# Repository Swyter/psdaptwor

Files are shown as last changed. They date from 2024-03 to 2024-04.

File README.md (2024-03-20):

# What is `psdaptwor`?
An experimental PC adapter for EPCOT —the PlayStation®VR2 headset— that splits USB Type-C® into DisplayPort video, USB 3 data and power. Intercepting its DP-AUX/SBU and CC side channels.

> **Important**: *This is my first electronics project and I am still ironing the whole thing out, I have gotten here with a lot of hints and reviews from people who actually know what they are doing, but it should be considered non-functional, for now.*

# How do I get one?
Once the project is properly tested and the design is finalized we will provide the manufacturing files to order assembled boards from any affordable printed circuit board (PCB) fabrication house.
The final aim of the project is that one assembled adapter should cost less than 50€; the design and components are being aggresively optimized as much as possible. Getting one or two should be feasible for almost anyone.

# What does it look like?
More or less like this, the dimensions are around *6.3 x 10.2 centimeters*; much tinier than it looks like here:

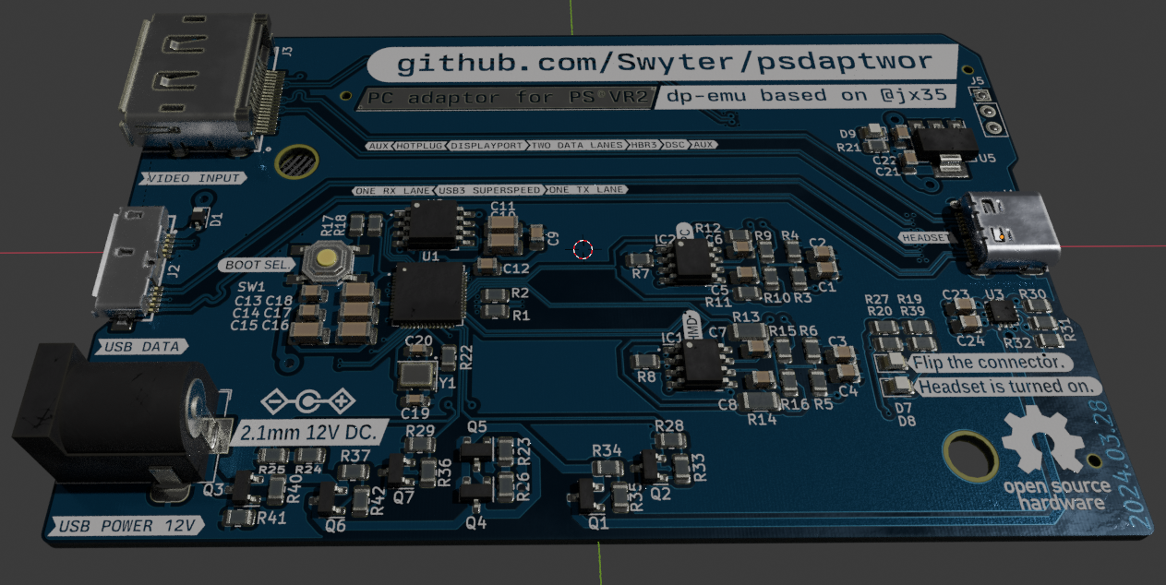
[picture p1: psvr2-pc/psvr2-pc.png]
imagen


# What is that name? Do you know how to spell?

No, it is not a typo. I needed something that could be unique and searchable, and contained `PS`, `VR` and `two` somewhere.
Sony products (like the memory card USB one) seem to call their adapters adaptors, so I follow their naming scheme.  

You can call it the *pee ess virtual adaptor*. :)

# Credits and acknowledgements
* *`@JX35`*: For the *DisplayPort AUX emulator* board this is heavily based on, and uncountable references, ideas and suggestions.
* *`@mrandTX`*: Hardware reviews, many suggestions, things I wouldn't have even thought about and encouragement.
* *`@thaytan`, `@ivry.vr` and many others around the Monado project*: Crucial research and development about how the PS®VR2 hardware and software actually functions. Standing on the shoulders of giants, this just cobbles stuff together. Many thanks.
* *[`jorticus/DPSwitch`](https://github.com/jorticus/DPSwitch)*, for the initial DisplayPort symbols and schematic that I used as a start point to learn the program and a good reference of how to use KiCad buses to group signals.
* *[`diva-eng/diva-card`](https://github.com/diva-eng/diva-card)*, for the known-good 12 MHz 20pF crystal oscillator circuit using cheap JLCPCB basic parts, and the capacitor/resistor values.

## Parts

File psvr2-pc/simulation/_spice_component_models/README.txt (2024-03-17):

https://www.nexperia.com/products/bipolar-transistors/general-purpose-and-low-vcesat-bipolar-transistors/single-bipolar-transistors/single-bipolar-transistors-100-v/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
https://assets.nexperia.com/documents/spice-model/MMBT2222A.txt

https://github.com/rdmeneze/LTSpiceModels/blob/master/AO3401A.mod

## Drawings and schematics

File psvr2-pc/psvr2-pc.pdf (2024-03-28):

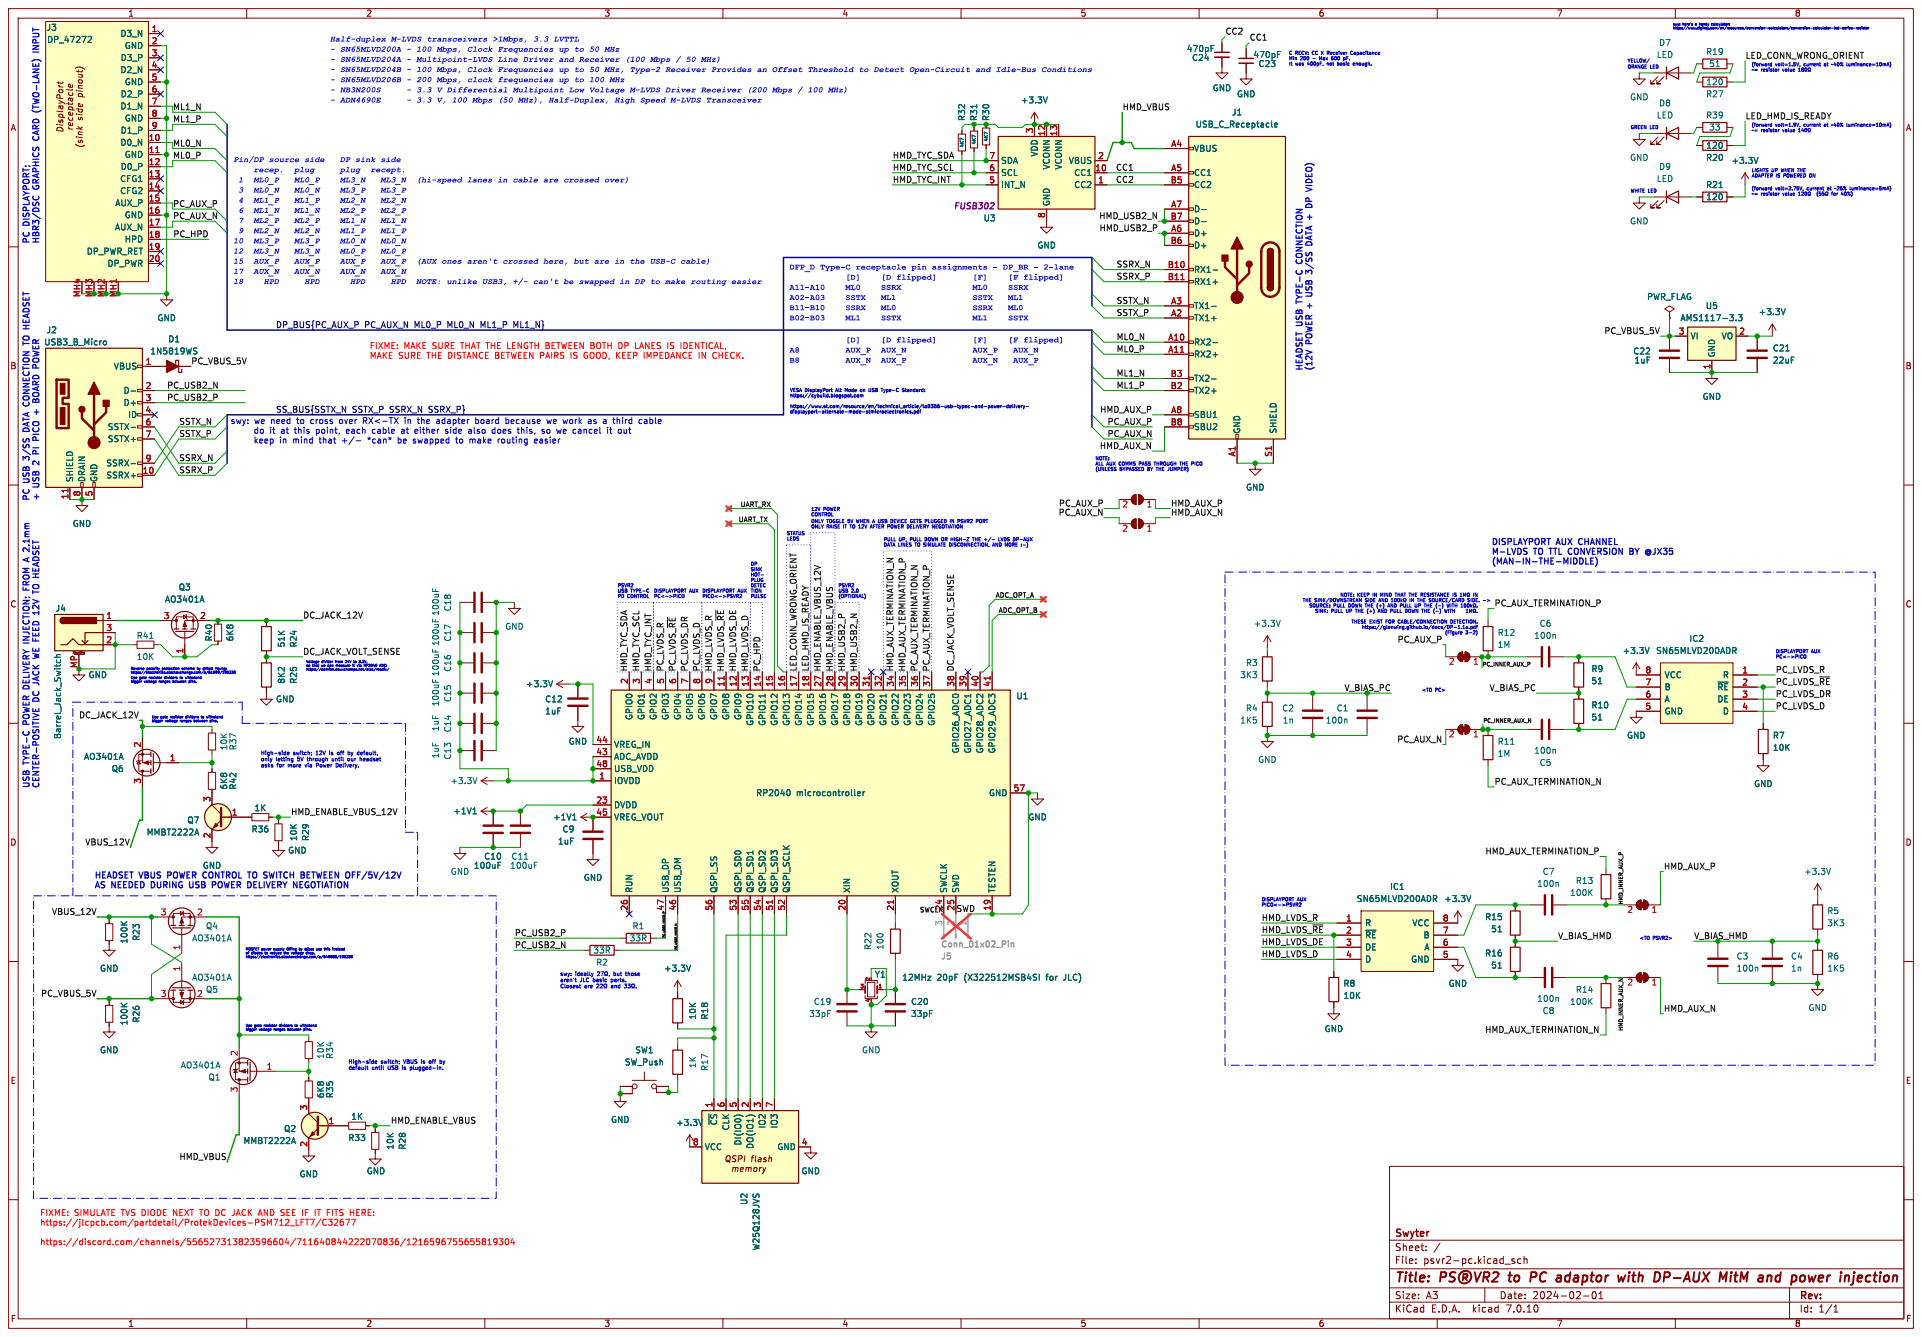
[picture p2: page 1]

(sink side pinout) GND 11 CFG1 13 CFG2 14 AUX_P 15 GND 16 AUX_N 17 HPD 18 DP_PWR_RET 19 GND 2 DP_PWR 20 GND 5 GND 8 MH4 MH3 MH2 MH1 D3_N 1 D0_N 10 D0_P 12 D3_P 3 D2_N 4 D2_P 6 D1_N 7 D1_P 9

- SN65MLVD200A - 100 Mbps, Clock Frequencies up to 50 MHz

C RECV: CC X Receiver Capacitance Min 200 þÿ"Max 600 pF.

1 R32 4K7 R30 4K7 R31 4K7 +3.3V U3 FUSB302 CC2 1 CC1 VCONN 10 12 VCONN 13 VBUS VDD 2

LIGHTS UP WHEN THE ADAPTER IS POWERED ON GREEN LED WHITE LED

+ USB 2 PI PICO + BOARD POWER

https://www.st.com/resource/en/technical_article/ta0356-usb-typec-and-power-delivery- displayport-alternate-mode-stmicroelectronics.pdf

NOTE: ALL AUX COMMS PASS THROUGH THE PICO

CONTROL HEADSET VBUS POWER CONTROL TO SWITCH BETWEEN OFF/5V/12V AS NEEDED DURING USB POWER DELIVERY NEGOTIATION

(Figure 3-2) ONLY TOGGLE 5V WHEN A USB DEVICE GETS PLUGGED IN PSVR2 PORT ONLY RAISE IT TO 12V AFTER POWER DELIVERY NEGOTIATION

NOTE: KEEP IN MIND THAT THE RESISTANCE IS þÿ1M©IN

2 XIN 20 XOUT 21 DVDD 23 SWCLK 24 SWD 25 RUN 26 GPIO16 27 GPIO17 28 GPIO18 29 GPIO1

<TO PSVR2> FIXME: SIMULATE TVS DIODE NEXT TO DC JACK AND SEE IF IT FITS HERE: https://jlcpcb.com/partdetail/ProtekDevices-PSM712_LFT7/C32677

Id: 1/1 Title: þÿPS®VR2 to PC adaptor with DP-AUX MitM and power injection

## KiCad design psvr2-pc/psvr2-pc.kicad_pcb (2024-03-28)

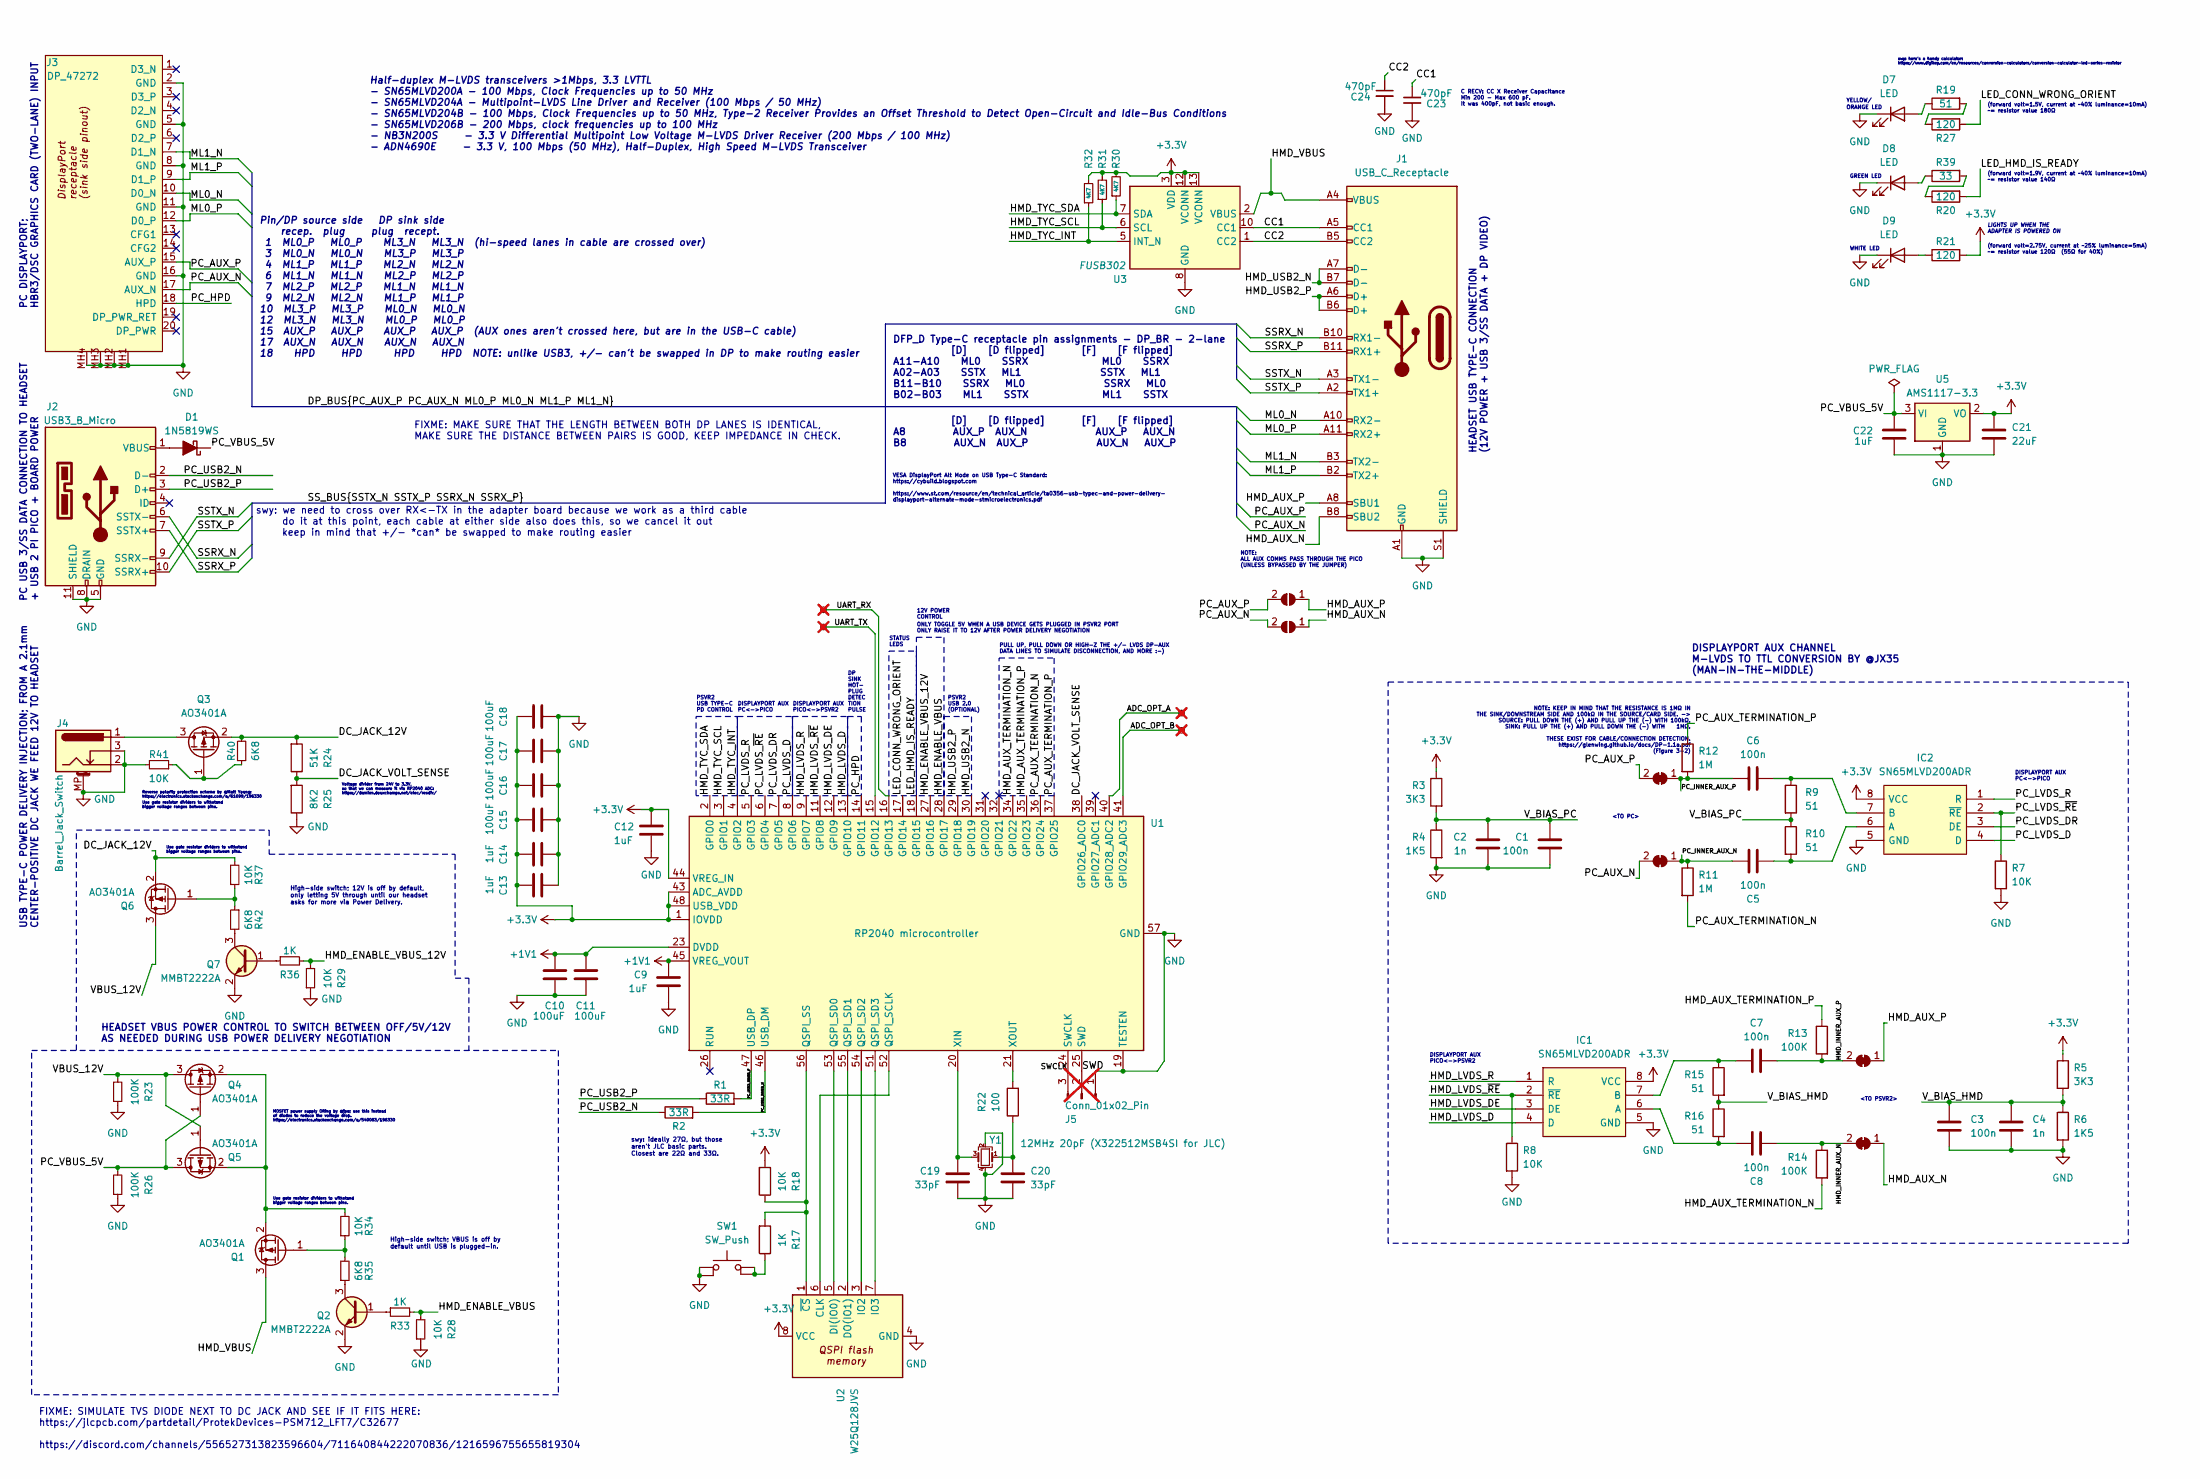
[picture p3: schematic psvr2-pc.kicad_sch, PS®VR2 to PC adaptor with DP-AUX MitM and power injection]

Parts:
C1, C3, C5, C6, C7, C8: 100n; C_0805_2012Metric
C2, C4: 1n; C_0805_2012Metric
C9, C12, C13, C14, C22: 1uF; C_0805_2012Metric
C10, C11, C15, C16, C17, C18: 100uF; C_1206_3216Metric
C19: 33pF; C_0603_1608Metric_Pad1.08x0.95mm_HandSolder; Mfr. Part # CL10C330JB8NNNC; LCSC Part # C1663
C20: 33pF; C_0603_1608Metric_Pad1.08x0.95mm_HandSolder; Mfr. Part # CL10C330JB8NNNC; JLCPCB Part # C1663
C21: 22uF; C_0805_2012Metric
C23, C24: 470pF; C_0805_2012Metric; LCSC Part # C1743
D1: 1N5819WS; D_SOD-323; Mfr. Part # 1N5819WS; LCSC Part # C191023
D7: LED; LED_0805_2012Metric; Mfr. Part # KT-0805Y; LCSC Part # C2296
D8: LED; LED_0805_2012Metric; Mfr. Part # KT-0805G; LCSC Part # C2297
D9: LED; LED_0805_2012Metric; Mfr. Part # KT-0805W; LCSC Part # C34499
IC1, IC2: SN65MLVD200ADR; SOIC-8_3.9x4.9mm_P1.27mm; Manufacturer_Part_Number SN65MLVD200ADR; Mouser Part Number 595-SN65MLVD200A
J1: USB_C_Receptacle; USB-C-SMD_TYPE-C-USB-18; Mfr. Part # MOLEX-1054500101; LCSC Part # C134092
J2: USB3_B_Micro; USB-SMD_692622030100
J3: DP_47272; CONN-SMD_472720001; LCSC Part # C587824
J4: Barrel_Jack_Switch; BarrelJack_Horizontal; Mfr. Part # DC-470-2.1GP; LCSC Part # C194407
J5: Conn_01x02_Pin; PinHeader_1x03_P2.54mm_Vertical; not fitted
JP1, JP2: SolderJumper_2_Open; SolderJumper-2_P1.3mm_Open_Pad1.0x1.5mm
JP3, JP5, JP6: SolderJumper_2_CLOSED; SolderJumper-2_P1.3mm_Bridged_RoundedPad1.0x1.5mm
JP4: SolderJumper_2_Open; SolderJumper-2_P1.3mm_Bridged_RoundedPad1.0x1.5mm
Q1, Q3, Q4, Q5, Q6: AO3401A; SOT-23; Mfr. Part # SI2301CDS-T1-GE3; JLCPCB Rotation Offset 180
Q2, Q7: MMBT2222A; SOT-23; Mfr. Part # MMBT2222A 1P; JLCPCB Rotation Offset 180
R1, R2: 33R; R_0805_2012Metric
R3, R5: 3K3; R_0805_2012Metric
R4, R6: 1K5; R_0805_2012Metric
R7, R8, R18, R28, R29, R34, R37, R41: 10K; R_0805_2012Metric
R9, R10, R15, R16, R19: 51; R_0805_2012Metric
R11, R12: 1M; R_0805_2012Metric
R13, R14: 100K; R_1206_3216Metric
R17, R33, R36: 1K; R_0805_2012Metric
R20, R21, R27: 120; R_0805_2012Metric
R22: 100; R_0805_2012Metric
R23, R26: 100K; R_0805_2012Metric
R24: 51K; R_0805_2012Metric
R25: 8K2; R_0805_2012Metric
R30, R31, R32: 4K7; R_0805_2012Metric
R35, R40, R42: 6K8; R_0805_2012Metric
R39: 33; R_0805_2012Metric
SW1: SW_Push; SW-SMD_4P-L5.1-W5.1-P3.70-LS6.5-TL-2; Mfr. Part # TS-1187A-B-A-B; LCSC Part # C318884
TP1, TP2, TP3, TP4: TestPoint_Small; TestPoint_Pad_D2.5mm; not fitted
U1: RP2040 microcontroller; QFN-56-1EP_7x7mm_P0.4mm_EP3.2x3.2mm; Mfr. Part # RP2040; LCSC Part # C2040
U2: W25Q128JVS; SOIC-8_5.23x5.23mm_P1.27mm; Mfr. Part # W25Q128JVSIQ; LCSC Part # C97521
U3: FUSB302B01MPX; WQFN-14-1EP_2.5x2.5mm_P0.5mm_EP1.45x1.45mm; Mfr. Part # Fusb302mpx; LCSC Part # C442699
U5: AMS1117-3.3; SOT-223-3_TabPin2; Mfr. Part # AMS1117-3.3; LCSC Part # C6186
Y1: 12MHz 20pF (X322512MSB4SI for JLC); Crystal_SMD_3225-4Pin_3.2x2.5mm; Mfr. Part # X322512MSB4SI; LCSC Part # C9002

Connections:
+1V1: C9.1, C10.1, C11.1, U1.23 (DVDD), U1.45 (VREG_VOUT), U1.50 (DVDD)
+3.3V: C12.1, C13.2, C14.2, C15.2, C16.2, C17.2, C18.2, C21.1, IC1.8 (VCC), IC2.8 (VCC), R3.1, R5.1, R18.2, R21.2, R30.2, R31.2, R32.2, U1.1 (IOVDD), U1.10 (IOVDD), U1.22 (IOVDD), U1.33 (IOVDD), U1.42 (IOVDD), U1.43 (ADC_AVDD), U1.44 (VREG_IN), U1.48 (USB_VDD), U1.49 (IOVDD), U2.8 (VCC), U3.3 (VDD), U3.4 (VDD), U3.12 (VCONN), U3.13 (VCONN), U5.2 (VO)
/ADC_OPT_A: TP3.1, U1.40 (GPIO28_ADC2)
/ADC_OPT_B: TP4.1, U1.41 (GPIO29_ADC3)
/CC1: C23.1, J1.A5 (CC1), U3.10 (CC1), U3.11 (CC1)
/CC2: C24.1, J1.B5 (CC2), U3.1 (CC2), U3.14 (CC2)
/DC_JACK_12V: Q3.2 (S), Q6.2 (S), R24.2, R37.2, R40.2
/DC_JACK_VOLT_SENSE: R24.1, R25.2, U1.38 (GPIO26_ADC0)
/HMD_AUX_N: J1.B8 (SBU2), JP2.1 (A), JP4.1 (A)
/HMD_AUX_P: J1.A8 (SBU1), JP1.1 (A), JP3.1 (A)
/HMD_AUX_TERMINATION_N: R14.2, U1.34 (GPIO22)
/HMD_AUX_TERMINATION_P: R13.1, U1.35 (GPIO23)
/HMD_ENABLE_VBUS: R28.2, R33.2, U1.28 (GPIO17)
/HMD_ENABLE_VBUS_12V: R29.2, R36.2, U1.27 (GPIO16)
/HMD_INNER_AUX_N: C8.2, JP4.2 (B), R14.1
/HMD_INNER_AUX_P: C7.2, JP3.2 (B), R13.2
/HMD_LVDS_D: IC1.4 (D), U1.13 (GPIO10)
/HMD_LVDS_DE: IC1.3 (DE), U1.12 (GPIO9)
/HMD_LVDS_R: IC1.1 (R), U1.9 (GPIO7)
/HMD_LVDS_~RE: IC1.2 (~RE), R8.1, U1.11 (GPIO8)
/HMD_TYC_INT: R32.1, U1.4 (GPIO2), U3.5 (INT_N)
/HMD_TYC_SCL: R31.1, U1.3 (GPIO1), U3.6 (SCL)
/HMD_TYC_SDA: R30.1, U1.2 (GPIO0), U3.7 (SDA)
/HMD_USB2_N: J1.A7 (D-), J1.B7 (D-), U1.30 (GPIO19)
/HMD_USB2_P: J1.A6 (D+), J1.B6 (D+), U1.29 (GPIO18)
/HMD_VBUS: J1.A4 (VBUS), J1.A9 (VBUS), J1.B4 (VBUS), J1.B9 (VBUS), Q1.3 (D), U3.2 (VBUS)
/LED_CONN_WRONG_ORIENT: R27.2, U1.17 (GPIO14)
/LED_HMD_IS_READY: R20.2, U1.18 (GPIO15)
/ML0_N: J1.A10 (RX2-), J3.10 (D0_N)
/ML0_P: J1.A11 (RX2+), J3.12 (D0_P)
/ML1_N: J1.B3 (TX2-), J3.7 (D1_N)
/ML1_P: J1.B2 (TX2+), J3.9 (D1_P)
/PC_AUX_N: J3.17 (AUX_N), JP2.2 (B), JP6.2 (B)
/PC_AUX_P: J3.15 (AUX_P), JP1.2 (B), JP5.2 (B)
/PC_AUX_TERMINATION_N: R11.2, U1.36 (GPIO24)
/PC_AUX_TERMINATION_P: R12.1, U1.37 (GPIO25)
/PC_HPD: J3.18 (HPD), U1.14 (GPIO11)
/PC_INNER_AUX_N: C5.2, JP6.1 (A), R11.1
/PC_INNER_AUX_P: C6.2, JP5.1 (A), R12.2
/PC_LVDS_D: IC2.4 (D), U1.8 (GPIO6)
/PC_LVDS_DR: IC2.3 (DE), U1.7 (GPIO5)
/PC_LVDS_R: IC2.1 (R), U1.5 (GPIO3)
/PC_LVDS_~RE: IC2.2 (~RE), R7.1, U1.6 (GPIO4)
/PC_USB2_INNER_N: R2.2, U1.46 (USB_DM)
/PC_USB2_INNER_P: R1.2, U1.47 (USB_DP)
/PC_USB2_N: J2.2 (D-), R2.1
/PC_USB2_P: J2.3 (D+), R1.1
/PC_VBUS_5V: C22.1, D1.1 (K), Q4.1 (G), Q5.3 (D), R26.2, U5.3 (VI)
/SSRX_N: J1.B10 (RX1-), J2.6 (SSTX-)
/SSRX_P: J1.B11 (RX1+), J2.7 (SSTX+)
/SSTX_N: J1.A3 (TX1-), J2.9 (SSRX-)
/SSTX_P: J1.A2 (TX1+), J2.10 (SSRX+)
/SWCLK: J5.3, U1.24 (SWCLK)
/SWD: J5.2, U1.25 (SWD)
/UART_RX: TP2.1, U1.16 (GPIO13)
/UART_TX: TP1.1, U1.15 (GPIO12)
/VBUS_12V: Q4.3 (D), Q5.1 (G), Q6.3 (D), R23.2
/V_BIAS_HMD: C3.1, C4.1, R5.2, R6.1, R15.2, R16.1
/V_BIAS_PC: C1.1, C2.1, R3.2, R4.1, R9.2, R10.1
GND: C1.2, C2.2, C3.2, C4.2, C9.2, C10.2, C11.2, C12.2, C13.1, C14.1, C15.1, C16.1, C17.1, C18.1, C19.2, C20.2, C21.2, C22.2, C23.2, C24.2, D7.1 (K), D8.1 (K), D9.1 (K), IC1.5 (GND), IC2.5 (GND), J1.0, J1.A1 (GND), J1.A12 (GND), J1.B1 (GND), J1.B12 (GND), J1.S1 (SHIELD), J2.5 (GND), J2.8 (DRAIN), J2.11 (SHIELD), J3.2 (GND), J3.5 (GND), J3.8 (GND), J3.11 (GND), J3.16 (GND), J3.21, J3.22, J3.23, J3.24, J3.MH1, J3.MH2, J3.MH3, J3.MH4, J4.2, J4.3, J4.MP (MountPin), J5.1, Q2.2 (E), Q7.2 (E), R4.2, R6.2, R7.2, R8.2, R23.1, R25.1, R26.1, R28.1, R29.1, R41.2, SW1.1, SW1.2, U1.19 (TESTEN), U1.57 (GND), U2.4 (GND), U3.8 (GND), U3.9 (GND), U3.15 (GND), U5.1 (GND), Y1.2, Y1.4
unnamed: C20.1, R22.1, Y1.1
unnamed: D1.2 (A), J2.1 (VBUS)
unnamed: D7.2 (A), R19.1
unnamed: D8.2 (A), R39.1
unnamed: D9.2 (A), R21.1
unnamed: C8.1, IC1.6 (A), R16.2
unnamed: C7.1, IC1.7 (B), R15.1
unnamed: C5.1, IC2.6 (A), R10.2
unnamed: C6.1, IC2.7 (B), R9.1
unnamed: Q1.1 (G), R34.1, R35.2
unnamed: Q1.2 (S), Q4.2 (S), Q5.2 (S), R34.2
unnamed: Q2.1 (B), R33.1
unnamed: Q2.3 (C), R35.1
unnamed: J4.1, Q3.3 (D)
unnamed: Q3.1 (G), R40.1, R41.1
unnamed: Q6.1 (G), R37.1, R42.1
unnamed: Q7.1 (B), R36.1
unnamed: Q7.3 (C), R42.2
unnamed: R17.1, SW1.3, SW1.4
unnamed: R19.2, R27.1
unnamed: R20.1, R39.2
unnamed: U1.52 (QSPI_SCLK), U2.6 (CLK)
unnamed: U1.53 (QSPI_SD0), U2.5 (DI(IO0))
unnamed: U1.55 (QSPI_SD1), U2.2 (DO(IO1))
unnamed: U1.54 (QSPI_SD2), U2.3 (IO2)
unnamed: U1.51 (QSPI_SD3), U2.7 (IO3)
unnamed: R17.2, R18.1, U1.56 (QSPI_SS), U2.1 (~CS)
unnamed: C19.1, U1.20 (XIN), Y1.3
unnamed: R22.2, U1.21 (XOUT)

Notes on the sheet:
Reverse polarity protection scheme by @Matt Young: https://electronics.stackexchange.com/a/61699/196330
NOTE: ALL AUX COMMS PASS THROUGH THE PICO (UNLESS BYPASSED BY THE JUMPER)
MOSFET power supply ORing by @jpa; use this instead of diodes to reduce the voltage drop. https://electronics.stackexchange.com/a/549083/196330
VESA DisplayPort Alt Mode on USB Type-C Standard: https://cybuild.blogspot.com https://www.st.com/resource/en/technical_article/ta0356-usb-typec-and-power-delivery- displayport-alternate-mode-stmicroelectronics.pdf
(forward volt=1.5V, current at ~40% luminance=10mA) ~= resistor value 180Ω
C RECV: CC X Receiver Capacitance Min 200 − Max 600 pF. It was 400pF, not basic enough.
DP SINK HOT- PLUG DETEC TION PULSE
HEADSET USB TYPE-C CONNECTION (12V POWER + USB 3/SS DATA + DP VIDEO)
DISPLAYPORT AUX CHANNEL M-LVDS TO TTL CONVERSION BY @JX35 (MAN-IN-THE-MIDDLE)
swy: we need to cross over RX<-TX in the adapter board because we work as a third cable do it at this point, each cable at either side also does this, so we cancel it out keep in mind that +/- *can* be swapped to make routing easier
DISPLAYPORT AUX PICO<->PSVR2
HEADSET VBUS POWER CONTROL TO SWITCH BETWEEN OFF/5V/12V AS NEEDED DURING USB POWER DELIVERY NEGOTIATION
WHITE LED
DISPLAYPORT AUX PC<->PICO
Voltage divider from 24V to 3.3V, so that we can measure it via RP2040 ADC: https://damien.douxchamps.net/elec/resdiv/
<TO PC>
12V POWER CONTROL
FIXME: MAKE SURE THAT THE LENGTH BETWEEN BOTH DP LANES IS IDENTICAL, MAKE SURE THE DISTANCE BETWEEN PAIRS IS GOOD, KEEP IMPEDANCE IN CHECK.
<TO PSVR2>
[D] [D flipped] [F] [F flipped] A8 AUX_P AUX_N AUX_P AUX_N B8 AUX_N AUX_P AUX_N AUX_P
Use gate resistor dividers to withstand bigger voltage ranges between pins.
High-side switch; 12V is off by default, only letting 5V through until our headset asks for more via Power Delivery.
YELLOW/
PULL UP, PULL DOWN OR HIGH-Z THE +/- LVDS DP-AUX DATA LINES TO SIMULATE DISCONNECTION, AND MORE :-)
(forward volt=2.75V, current at ~25% luminance=5mA) ~= resistor value 120Ω (55Ω for 40%)
(forward volt=1.9V, current at ~40% luminance=10mA) ~= resistor value 140Ω
ONLY TOGGLE 5V WHEN A USB DEVICE GETS PLUGGED IN PSVR2 PORT ONLY RAISE IT TO 12V AFTER POWER DELIVERY NEGOTIATION
ORANGE LED
swy: here's a handy calculator: https://www.digikey.com/en/resources/conversion-calculators/conversion-calculator-led-series-resistor
swy: ideally 27Ω, but those aren't JLC basic parts. Closest are 22Ω and 33Ω.
FIXME: SIMULATE TVS DIODE NEXT TO DC JACK AND SEE IF IT FITS HERE: https://jlcpcb.com/partdetail/ProtekDevices-PSM712_LFT7/C32677 https://discord.com/channels/556527313823596604/711640844222070836/1216596755655819304
PSVR2 USB 2.0 (OPTIONAL)
USB TYPE-C POWER DELIVERY INJECTION; FROM A 2.1mm CENTER-POSITIVE DC JACK WE FEED 12V TO HEADSET
Pin/DP source side DP sink side recep. plug plug recept. 1 ML0_P ML0_P ML3_N ML3_N (hi-speed lanes in cable are crossed over) 3 ML0_N ML0_N ML3_P ML3_P 4 ML1_P ML1_P ML2_N ML2_N 6 ML1_N ML1_N ML2_P ML2_P 7 ML2_P ML2_P ML1_N ML1_N 9 ML2_N ML2_N ML1_P ML1_P 10 ML3_P ML3_P ML0_N ML0_N 12 ML3_N ML3_N M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
Half-duplex M-LVDS transceivers >1Mbps, 3.3 LVTTL - SN65MLVD200A - 100 Mbps, Clock Frequencies up to 50 MHz - SN65MLVD204A - Multipoint-LVDS Line Driver and Receiver (100 Mbps / 50 MHz) - SN65MLVD204B - 100 Mbps, Clock Frequencies up to 50 MHz, Type-2 Receiver Provides an Offset Threshold to Detect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
STATUS LEDS
PC USB 3/SS DATA CONNECTION TO HEADSET + USB 2 PI PICO + BOARD POWER
NOTE: KEEP IN MIND THAT THE RESISTANCE IS 1MΩ IN THE SINK/DOWNSTREAM SIDE AND 100kΩ IN THE SOURCE/CARD SIDE. -> SOURCE: PULL DOWN THE (+) AND PULL UP THE (-) WITH 100kΩ. SINK: PULL UP THE (+) AND PULL DOWN THE (-) WITH 1MΩ. THESE EXIST FOR CABLE/CONNECTION DETECTION. https://glenwing.github.io/docs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
High-side switch; VBUS is off by default until USB is plugged-in.
DFP_D Type-C receptacle pin assignments - DP_BR - 2-lane [D] [D flipped] [F] [F flipped] A11-A10 ML0 SSRX ML0 SSRX A02-A03 SSTX ML1 SSTX ML1 B11-B10 SSRX ML0 SSRX ML0 B02-B03 ML1 SSTX ML1 SSTX

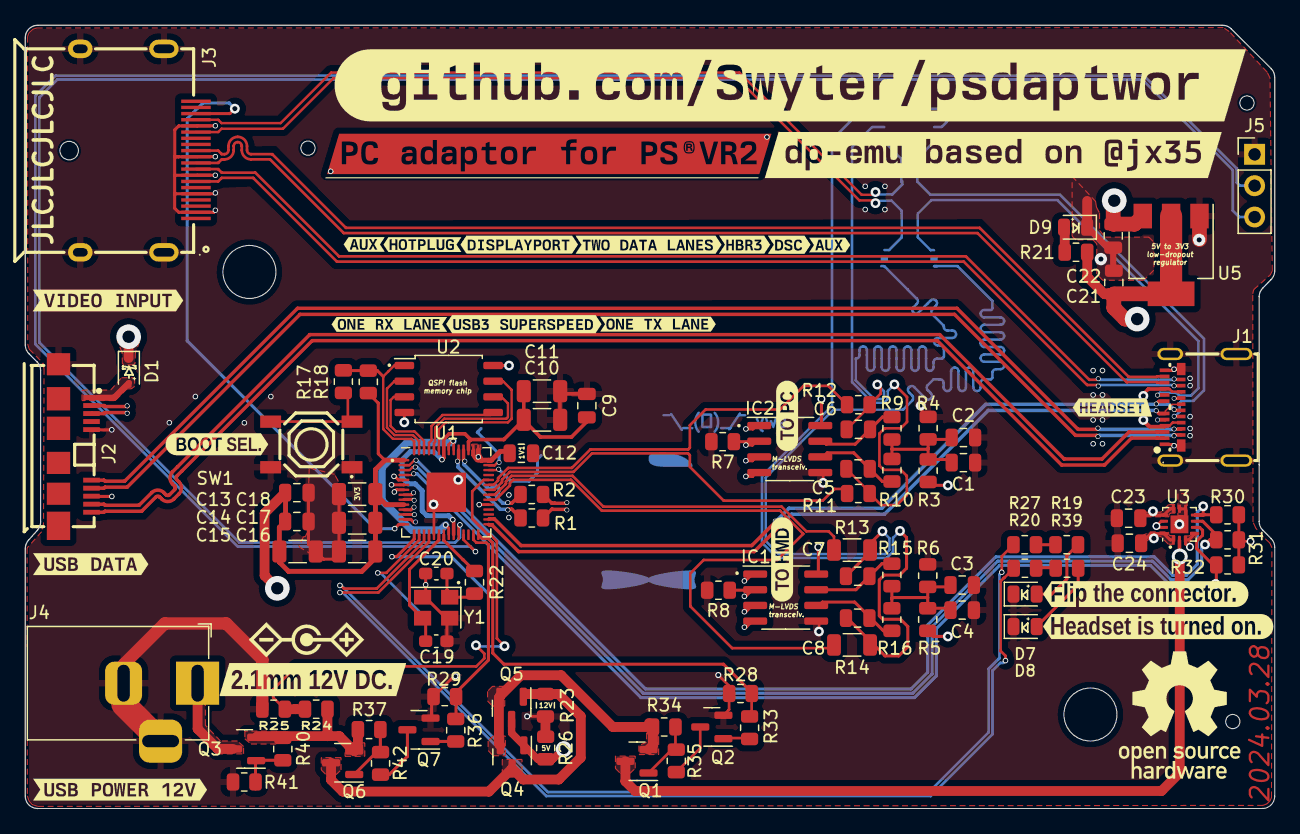
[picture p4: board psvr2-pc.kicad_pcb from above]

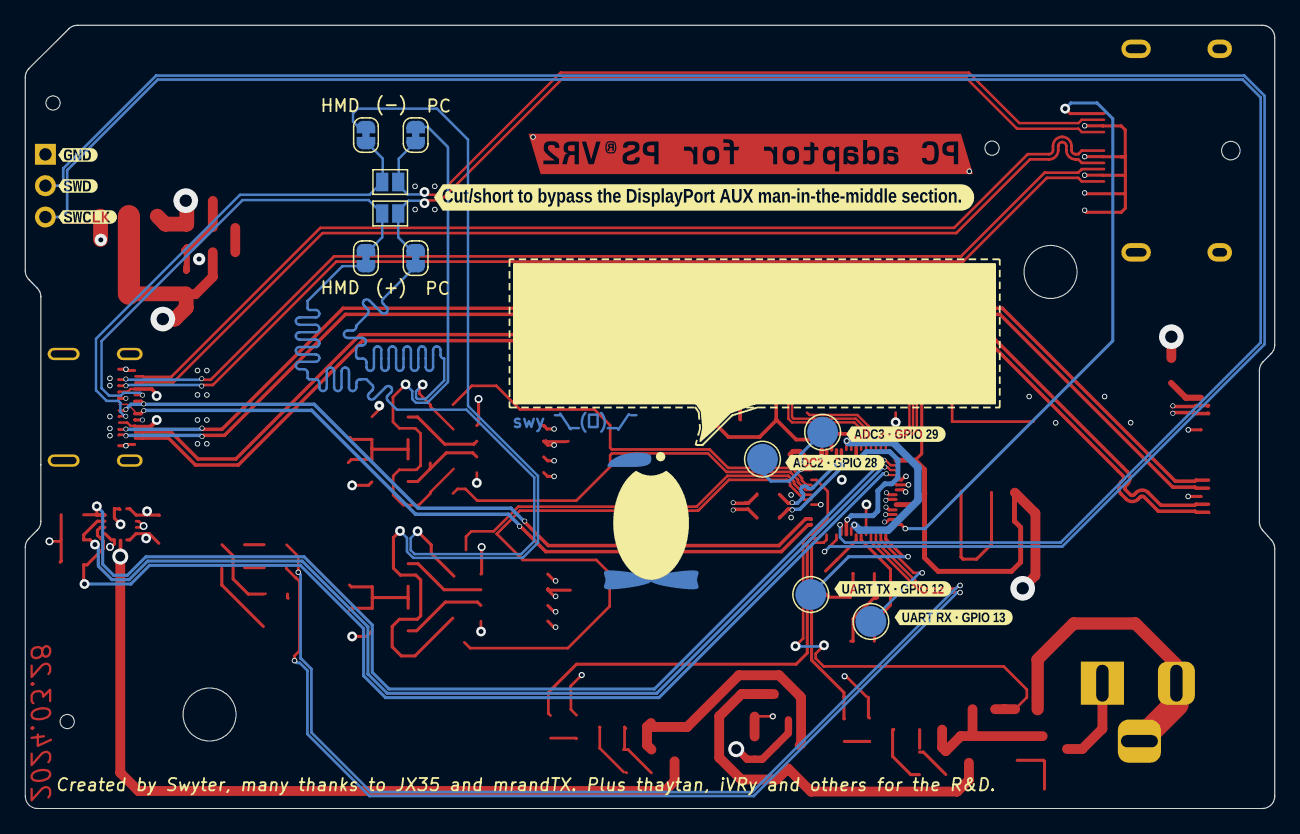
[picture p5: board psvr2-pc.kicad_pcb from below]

Board: 4 copper layers, 101.3 x 63.5 mm, 135 parts (18 on the bottom side), 89 nets.

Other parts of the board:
M4_MOUNT_HOLE_DOWN, M4_MOUNT_HOLE_UP: MountingHole_4.3mm_M4
SMT_BOTTOM_RIGHT: MountingHole_2.1mm
SMT_TOP_LEFT: MountingHole_2.1mm
SMT_TOP_RIGHT: MountingHole_2.1mm
kibuzzard-65C6E5E2: G***; kibuzzard-65C6E5E2
kibuzzard-65C6E540: G***; kibuzzard-65C6E540
kibuzzard-65C0700D: G***; kibuzzard-65C0700D
kibuzzard-65C07004: G***; kibuzzard-65C07004
kibuzzard-65C07017: G***; kibuzzard-65C07017
kibuzzard-65E1F822: G***; kibuzzard-65E1F822
kibuzzard-65E1F853: G***; kibuzzard-65E1F853
kibuzzard-65E1FEE7: G***; kibuzzard-65E1FEE7
kibuzzard-65E1FEEE: G***; kibuzzard-65E1FEEE
kibuzzard-65E1FFC8: G***; kibuzzard-65E1FFC8
kibuzzard-65E7A09E: G***; kibuzzard-65E7A09E
kibuzzard-65E7A091: G***; kibuzzard-65E7A091
kibuzzard-65E7B531: G***; kibuzzard-65E7B531
kibuzzard-65E009D7: G***; kibuzzard-65E009D7
kibuzzard-65E024DE: G***; kibuzzard-65E024DE
kibuzzard-65E0054E: G***; kibuzzard-65E0054E
kibuzzard-65E91FE7: G***; kibuzzard-65E91FE7
kibuzzard-65E539B1: G***; kibuzzard-65E539B1
kibuzzard-65E00649: G***; kibuzzard-65E00649
kibuzzard-65E00656: G***; kibuzzard-65E00656
kibuzzard-65E00723: G***; kibuzzard-65E00723
kibuzzard-65E00862: G***; kibuzzard-65E00862
kibuzzard-65E00873: G***; kibuzzard-65E00873
kibuzzard-65E00902: G***; kibuzzard-65E00902
kibuzzard-65E00968: G***; kibuzzard-65E00968
kibuzzard-65E01491: G***; kibuzzard-65E01491
kibuzzard-65E20367: G***; kibuzzard-65E20367
kibuzzard-65EB850B: G***; kibuzzard-65EB850B
kibuzzard-65EB8511: G***; kibuzzard-65EB8511
kibuzzard-65F67D58: G***; kibuzzard-65F67D58
kibuzzard-65F683C1: G***; kibuzzard-65F683C1

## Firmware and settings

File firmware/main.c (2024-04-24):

/**
 * | psdaptwor - an experimental PSVR2 to PC adaptor | firmware
 * | created by Swyter <swyterzone+psdaptwor@gmail.com>
 *
 * SPDX-License-Identifier: GPL-2.0-or-later
 */

#include <stdio.h>
#include <stdlib.h>
#include <string.h>
#include <tusb.h>
#include "pico/stdlib.h"
#include "hardware/gpio.h"
#include "hardware/adc.h"

#include "pico/binary_info.h"
#include "hardware/i2c.h"

#include "fusb302_defines.h"
//#include "pd.h"

/*      Main microcontroller chip: https://datasheets.raspberrypi.com/rp2040/rp2040-datasheet.pdf
                                   https://datasheets.raspberrypi.com/rp2040/hardware-design-with-rp2040.pdf

        Type-C PD controller chip: https://www.onsemi.com/pdf/datasheet/fusb302b-d.pdf
                                   https://github.com/Ralim/usb-pd/
                                   https://www.ti.com/lit/an/slva704/slva704.pdf (good overview of how the I2C protocol works)
                                   https://github.com/ReclaimerLabs/FUSB302/blob/master/FUSB302.cpp (The Google ChromeOS EC implementation; very clean and well-commented)
                                   https://hackaday.com/2023/02/14/all-about-usb-c-talking-low-level-pd/ (init and receiving PD messages as a UFP/sink)
                                   https://hackaday.com/2023/02/22/all-about-usb-c-replying-low-level-pd/ (sending [accept] messages)
                                   https://github.com/CRImier/AltmodeFriend/blob/main/main.py (RP2040 micropython implementation from the Hackaday author)

   M-LVDS to TTL transceiver chip: http://www.ti.com/lit/gpn/SN65MLVD200 */

enum psdaptwor_pins
{
    PSDAPT_PIN_HMD_TYC_SDA           =  0, /* swy: I2C connection to FUSB302B Type-C Power Delivery control chip */
    PSDAPT_PIN_HMD_TYC_SCL           =  1,
    PSDAPT_PIN_HMD_TYC_INT           =  2,
          
    PSDAPT_PIN_PC_LVDS_R             =  3, /* swy: M-LVDS transceiver data in-out for both DisplayPort AUX sides */
    PSDAPT_PIN_PC_LVDS_RE            =  4,
    PSDAPT_PIN_PC_LVDS_DR            =  5,
    PSDAPT_PIN_PC_LVDS_D             =  6,
          
    PSDAPT_PIN_HMD_LVDS_R            =  7,
    PSDAPT_PIN_HMD_LVDS_RE           =  8,
    PSDAPT_PIN_HMD_LVDS_DR           =  9,
    PSDAPT_PIN_HMD_LVDS_D            = 10,

    /* -- */

    PSDAPT_PIN_PC_HPD                = 11, /* swy: DisplayPort hot-plug detection pulse signal */
//  PSDAPT_PIN_12_UNUSED             = 12,
//  PSDAPT_PIN_13_UNUSED             = 13,

    PSDAPT_PIN_LED_CONN_WRONG_ORIENT = 14, /* swy: status LEDS; wrong-type-c-orientation is orange */
    PSDAPT_PIN_LED_HMD_IS_READY      = 15, /*                           headset-is-ready is green  */

    PSDAPT_PIN_HMD_ENABLE_VBUS_12V   = 16, /* swy: control the power switches by software as needed to enable */
    PSDAPT_PIN_HMD_ENABLE_VBUS       = 17, /*      the higher 12V DC jack voltage/5V from PC/off              */

    PSDAPT_PIN_HMD_USB2_P            = 18, /* swy: connected to the headset's USB 2.0 +/- pair, optional, in case we want to */
    PSDAPT_PIN_HMD_USB2_N            = 19, /*      relay it to the host PC via PIO, or inspect the billboard device          */
//  PSDAPT_PIN_20_UNUSED             = 20,
//  PSDAPT_PIN_21_UNUSED             = 21,

    PSDAPT_PIN_AUX_TERMINATION_N     = 22, /* swy: M-LVDS transceiver software-defined pull-up and pull-down resistors */
    PSDAPT_PIN_AUX_TERMINATION_P     = 23,
    PSDAPT_PIN_PC_AUX_TERMINATION_N  = 24,
    PSDAPT_PIN_PC_AUX_TERMINATION_P  = 25,

    PSDAPT_PIN_DC_JACK_VOLT_SENSE    = 26, /* swy: analog-to-digital converter pins */
//  PSDAPT_PIN_27_UNUSED             = 27,
    PSDAPT_PIN_ADC_OPT_A             = 28,
    PSDAPT_PIN_ADC_OPT_B             = 29,
};

// I2C reserves some addresses for special purposes. We exclude these from the scan.
// These are any addresses of the form 000 0xxx or 111 1xxx

bool reserved_addr(uint8_t addr) {
    return (addr & 0x78) == 0 || (addr & 0x78) == 0x78;
}
 

/* swy: I2C register reading/writing functions from: https://forums.raspberrypi.com/viewtopic.php?p=2040653#p2040598 */
// Read bytes from a register
int i2c_read(
    i2c_inst_t *i2c,   // i2c0 or i2c1
    uint8_t i2c_addr,  // 7 bit I2C address
    uint8_t reg,       // Number of the register to read from
    uint8_t *rx_data,  // Pointer to block of bytes for data read
    uint8_t len        // Number of bytes of data to read
) {
    if (i2c_write_blocking(i2c, i2c_addr, &reg, 1, true) != 1) {
        return PICO_ERROR_GENERIC;
    }

    if (i2c_read_blocking(i2c, i2c_addr, rx_data, len, false) != len) {
        return PICO_ERROR_GENERIC;
    }

    return PICO_OK;
}

int i2c_read_byte(
    i2c_inst_t *i2c,   // i2c0 or i2c1
    uint8_t i2c_addr,  // 7 bit I2C address
    uint8_t reg,       // Number of the register to read from
    uint8_t *rx_data   // Pointer to block of bytes for data read
) {
    return i2c_read(i2c, i2c_addr, reg, rx_data, 1);
}

// Write bytes to a register
int i2c_write(
    i2c_inst_t *i2c,         // i2c0 or i2c1
    uint8_t i2c_addr,        // 7 bit I2C address 
    uint8_t reg,             // Number of the register to write to
    const uint8_t *tx_data,  // Pointer to block of bytes to write
    uint8_t len              // Length of block of bytes to write
) {
    uint8_t tx_len = len + 1;
    uint8_t tx_buf[tx_len];
    tx_buf[0]  = reg;
    memcpy(&tx_buf[1], tx_data, len);

    if (i2c_write_blocking(i2c, i2c_addr, tx_buf, tx_len, false) != tx_len) {
        return PICO_ERROR_GENERIC;
    }

    return PICO_OK;
}

int i2c_write_byte(
    i2c_inst_t *i2c,         // i2c0 or i2c1
    uint8_t i2c_addr,        // 7 bit I2C address 
    uint8_t reg,             // Number of the register to write to
    uint8_t tx_byte          // Byte to write
) {
    uint8_t tx_buf = tx_byte; return i2c_write(i2c, i2c_addr, reg, &tx_buf, 1);
}


char *fusb_debug_register(uint8_t reg, uint8_t reg_data)
{
    uint8_t reg_data_orig = reg_data;

#define CASE_PRINT(_REG) \
    case _REG: printf("[%s]: ", &#_REG[5]);

#define PRINT_REG(ARG_PREFIX, ARG_NAME) /* swy: if the flag is set, print it, to see if we need to print a | separator make sure the current flag is set and there's any set data underneath that will be processed afterwards, or we'll just print the number */ \
    printf("%s%s", (reg_data & ARG_PREFIX##_##ARG_NAME) ? #ARG_NAME : "", (reg_data & ARG_PREFIX##_##ARG_NAME) && (reg_data & (ARG_PREFIX##_##ARG_NAME - 1)) ? "|" : ""); reg_data &= ~ARG_PREFIX##_##ARG_NAME;

#define CASE_END() \
    if (reg_data != 0 || reg_data_orig==reg_data) printf("%#x, ", reg_data); /* swy: if there's any remaining unparsed data, or no flags have been processed, i.e. it's zero, print the number */ \
                                             else printf(  ", "); \
    break;

    switch (reg)
    {
        default:
            printf("[??? Unknown register %X], ", reg);
            break;

        CASE_PRINT(FUSB_SWITCHES0) {
            PRINT_REG(FUSB_SWITCHES0, CC2_PU_EN)
            PRINT_REG(FUSB_SWITCHES0, CC1_PU_EN)
            PRINT_REG(FUSB_SWITCHES0, VCONN_CC2)
            PRINT_REG(FUSB_SWITCHES0, VCONN_CC1)
            PRINT_REG(FUSB_SWITCHES0, MEAS_CC2 )
            PRINT_REG(FUSB_SWITCHES0, MEAS_CC1 )
            PRINT_REG(FUSB_SWITCHES0, CC2_PD_EN)
            PRINT_REG(FUSB_SWITCHES0, CC1_PD_EN)
            CASE_END()
        }

        CASE_PRINT(FUSB_SWITCHES1) {
            PRINT_REG(FUSB_SWITCHES1, POWERROLE)
            PRINT_REG(FUSB_SWITCHES1, SPECREV1 )
            PRINT_REG(FUSB_SWITCHES1, SPECREV0 )
            PRINT_REG(FUSB_SWITCHES1, DATAROLE )
            PRINT_REG(FUSB_SWITCHES1, AUTO_CRC )
            PRINT_REG(FUSB_SWITCHES1, TXCC2_EN )
            PRINT_REG(FUSB_SWITCHES1, TXCC1_EN )
            CASE_END()
        }

        CASE_PRINT(FUSB_CONTROL0) {
            PRINT_REG(FUSB_CONTROL0, TX_FLUSH )
            PRINT_REG(FUSB_CONTROL0, INT_MASK )
            PRINT_REG(FUSB_CONTROL0, HOST_CUR1)
            PRINT_REG(FUSB_CONTROL0, HOST_CUR0)
            PRINT_REG(FUSB_CONTROL0, AUTO_PRE )
            PRINT_REG(FUSB_CONTROL0, TX_START )
            CASE_END()
        }

        CASE_PRINT(FUSB_CONTROL1) {
            PRINT_REG(FUSB_CONTROL1, ENSOP2DB  )
            PRINT_REG(FUSB_CONTROL1, ENSOP1DB  )
            PRINT_REG(FUSB_CONTROL1, BIST_MODE2)
            PRINT_REG(FUSB_CONTROL1, RX_FLUSH  )
            PRINT_REG(FUSB_CONTROL1, ENSOP2    )
            PRINT_REG(FUSB_CONTROL1, ENSOP1    )
            CASE_END()
        }

        CASE_PRINT(FUSB_CONTROL2) {
            PRINT_REG(FUSB_CONTROL2, TOG_SAVE_PWR1)
            PRINT_REG(FUSB_CONTROL2, TOG_SAVE_PWR0)
            PRINT_REG(FUSB_CONTROL2, TOG_RD_ONLY  )
            PRINT_REG(FUSB_CONTROL2, WAKE_EN      )
            PRINT_REG(FUSB_CONTROL2, MODE1        )
            PRINT_REG(FUSB_CONTROL2, MODE0        )
            PRINT_REG(FUSB_CONTROL2, TOGGLE       )
            CASE_END()
        }

        CASE_PRINT(FUSB_CONTROL3) {
            PRINT_REG(FUSB_CONTROL3, SEND_HARD_RESET)
            PRINT_REG(FUSB_CONTROL3, BIST_TMODE     )
            PRINT_REG(FUSB_CONTROL3, AUTO_HARDRESET )
            PRINT_REG(FUSB_CONTROL3, AUTO_SOFTRESET )
            PRINT_REG(FUSB_CONTROL3, N_RETRIES1     )
            PRINT_REG(FUSB_CONTROL3, N_RETRIES0     )
            PRINT_REG(FUSB_CONTROL3, AUTO_RETRY     )
            CASE_END()
        }

        CASE_PRINT(FUSB_POWER) {
            PRINT_REG(FUSB_POWER, PWR3)
            PRINT_REG(FUSB_POWER, PWR2)
            PRINT_REG(FUSB_POWER, PWR1)
            PRINT_REG(FUSB_POWER, PWR0)
            CASE_END()
        }

        CASE_PRINT(FUSB_STATUS0A) {
            PRINT_REG(FUSB_STATUS0A, SOFTFAIL )
            PRINT_REG(FUSB_STATUS0A, RETRYFAIL)
            PRINT_REG(FUSB_STATUS0A, POWER3   )
            PRINT_REG(FUSB_STATUS0A, POWER2   )
            PRINT_REG(FUSB_STATUS0A, SOFTRST  )
            PRINT_REG(FUSB_STATUS0A, HARDRST  )
            CASE_END()
        }

        CASE_PRINT(FUSB_STATUS1A) {
            PRINT_REG(FUSB_STATUS1A, TOGSS_SHIFT)
            PRINT_REG(FUSB_STATUS1A, TOGSS      )
            PRINT_REG(FUSB_STATUS1A, RXSOP2DB   )
            PRINT_REG(FUSB_STATUS1A, RXSOP1DB   )
            PRINT_REG(FUSB_STATUS1A, RXSOP      )
            CASE_END()
        }

        CASE_PRINT(FUSB_INTERRUPTA) {
            PRINT_REG(FUSB_INTERRUPTA, I_OCP_TEMP )
            PRINT_REG(FUSB_INTERRUPTA, I_TOGDONE  )
            PRINT_REG(FUSB_INTERRUPTA, I_SOFTFAIL )
            PRINT_REG(FUSB_INTERRUPTA, I_RETRYFAIL)
            PRINT_REG(FUSB_INTERRUPTA, I_HARDSENT )
            PRINT_REG(FUSB_INTERRUPTA, I_TXSENT   )
            PRINT_REG(FUSB_INTERRUPTA, I_SOFTRST  )
            PRINT_REG(FUSB_INTERRUPTA, I_HARDRST  )
            CASE_END()
        }

        CASE_PRINT(FUSB_INTERRUPTB) {
            PRINT_REG(FUSB_INTERRUPTB, I_GCRCSENT)
            CASE_END()
        }

        CASE_PRINT(FUSB_STATUS0) {
            PRINT_REG(FUSB_STATUS0, VBUSOK  )
            PRINT_REG(FUSB_STATUS0, ACTIVITY)
            PRINT_REG(FUSB_STATUS0, COMP    )
            PRINT_REG(FUSB_STATUS0, CRC_CHK )
            PRINT_REG(FUSB_STATUS0, ALERT   )
            PRINT_REG(FUSB_STATUS0, WAKE    )
            PRINT_REG(FUSB_STATUS0, BC_LVL1 )
            PRINT_REG(FUSB_STATUS0, BC_LVL0 )
            CASE_END()
        }

        CASE_PRINT(FUSB_STATUS1) {
            PRINT_REG(FUSB_STATUS1, RXSOP2  )
            PRINT_REG(FUSB_STATUS1, RXSOP1  )
            PRINT_REG(FUSB_STATUS1, RX_EMPTY)
            PRINT_REG(FUSB_STATUS1, RX_FULL )
            PRINT_REG(FUSB_STATUS1, TX_EMPTY)
            PRINT_REG(FUSB_STATUS1, TX_FULL )
            PRINT_REG(FUSB_STATUS1, OVRTEMP )
            PRINT_REG(FUSB_STATUS1, OCP     )
            CASE_END()
        }

        CASE_PRINT(FUSB_INTERRUPT) {
            PRINT_REG(FUSB_INTERRUPT, I_VBUSOK   )
            PRINT_REG(FUSB_INTERRUPT, I_ACTIVITY )
            PRINT_REG(FUSB_INTERRUPT, I_COMP_CHNG)
            PRINT_REG(FUSB_INTERRUPT, I_CRC_CHK  )
            PRINT_REG(FUSB_INTERRUPT, I_ALERT    )
            PRINT_REG(FUSB_INTERRUPT, I_WAKE     )
            PRINT_REG(FUSB_INTERRUPT, I_COLLISION)
            PRINT_REG(FUSB_INTERRUPT, I_BC_LVL   )
            CASE_END()
        }

    }
#undef CASE_END
#undef PRINT_REG
#undef CASE_PRINT
}

uint32_t fusb_interrupt_callback_happened = 0;
uint8_t dat_int_a, dat_int_b, dat_int, dat_stat1;
bool run_replug = true;

absolute_time_t before = 0;

void fusb_interrupt_callback(uint gpio, uint32_t event_mask)
{
    before = get_absolute_time();printf("\nget_absolute_time %lu\n", before);
    fusb_interrupt_callback_happened = event_mask;
}


int fusb_measure_against(int mdac_val)
{
    uint8_t rxdata, ret = i2c_write_byte(i2c_default, FUSB302B_ADDR, FUSB_MEASURE, FUSB_MEASURE_MEAS_VBUS | (mdac_val & 0b111111)); //printf("f write ret: %#x, counter: %x, comp volt: %f\n", ret, mdac_val, mdac_val * 0.420f);
    i2c_read(i2c_default, FUSB302B_ADDR, FUSB_STATUS0, &rxdata, 1); //printf("i2c_read FUSB_STATUS0: %#x COMP: %u\n", rxdata, (rxdata & FUSB_STATUS0_COMP));
    return (rxdata & FUSB_STATUS0_COMP);
}

int fusb_measure_vbus_bsearch_comp(const void *a, const void *b)
{
    long unsigned int index = (long unsigned int) b;

    if ((fusb_measure_against(index) & FUSB_STATUS0_COMP) && index < (FUSB_MEASURE_MDAC + 1))
        return (fusb_measure_against(index + 1) == 0) ? 0 : +1;

    return -1;
}
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
int main() {
    stdio_init_all();
    stdio_usb_init();
    stdio_usb_connected();
    printf("ADC Example, measuring GPIO26\n");

    set_sys_clock_khz(160000, true);

#ifndef PICO_DEFAULT_LED_PIN
#warning blink example requires a board with a regular LED
#else
    const uint LED_PIN = PICO_DEFAULT_LED_PIN;
    gpio_init   (PSDAPT_PIN_LED_CONN_WRONG_ORIENT);
    gpio_set_dir(PSDAPT_PIN_LED_CONN_WRONG_ORIENT, GPIO_OUT);
    gpio_put    (PSDAPT_PIN_LED_CONN_WRONG_ORIENT, 1);

    gpio_init   (PSDAPT_PIN_LED_HMD_IS_READY);
    gpio_set_dir(PSDAPT_PIN_LED_HMD_IS_READY, GPIO_OUT);
    gpio_put    (PSDAPT_PIN_LED_HMD_IS_READY, 1);
#endif

    gpio_init   (PSDAPT_PIN_HMD_ENABLE_VBUS);
    gpio_set_dir(PSDAPT_PIN_HMD_ENABLE_VBUS, GPIO_OUT);
    gpio_put    (PSDAPT_PIN_HMD_ENABLE_VBUS,     0);

    gpio_init   (PSDAPT_PIN_HMD_ENABLE_VBUS_12V);
    gpio_set_dir(PSDAPT_PIN_HMD_ENABLE_VBUS_12V, GPIO_OUT);
    gpio_put    (PSDAPT_PIN_HMD_ENABLE_VBUS_12V, 0);

    gpio_init   (PSDAPT_PIN_PC_HPD);
    gpio_set_dir(PSDAPT_PIN_PC_HPD, GPIO_OUT);
    gpio_put    (PSDAPT_PIN_PC_HPD, 0);

    gpio_init         (PSDAPT_PIN_HMD_USB2_P);
    gpio_set_dir      (PSDAPT_PIN_HMD_USB2_P, GPIO_IN);
    gpio_disable_pulls(PSDAPT_PIN_HMD_USB2_P);
    gpio_init         (PSDAPT_PIN_HMD_USB2_N);
    gpio_set_dir      (PSDAPT_PIN_HMD_USB2_N, GPIO_IN);
    gpio_disable_pulls(PSDAPT_PIN_HMD_USB2_N);

    sleep_ms(3500);    

    adc_init();

    // Make sure GPIO is high-impedance, no pullups etc
    adc_gpio_init(26);
    // Select ADC input 0 (GPIO26)
    adc_select_input(0);


    // This example will use I2C0 on the default SDA and SCL pins (GP4, GP5 on a Pico)
    i2c_init(i2c_default, 400000);
    gpio_set_function(PICO_DEFAULT_I2C_SDA_PIN, GPIO_FUNC_I2C);
    gpio_set_function(PICO_DEFAULT_I2C_SCL_PIN, GPIO_FUNC_I2C);
    gpio_pull_up(PICO_DEFAULT_I2C_SDA_PIN);
    gpio_pull_up(PICO_DEFAULT_I2C_SCL_PIN);
    // Make the I2C pins available to picotool
    bi_decl(bi_2pins_with_func(PICO_DEFAULT_I2C_SDA_PIN, PICO_DEFAULT_I2C_SCL_PIN, GPIO_FUNC_I2C));

    gpio_set_irq_enabled_with_callback(PSDAPT_PIN_HMD_TYC_INT, GPIO_IRQ_EDGE_FALL, true, fusb_interrupt_callback);


    printf("\nI2C Bus Scan test\n");
    printf("   0  1  2  3  4  5  6  7  8  9  A  B  C  D  E  F\n");
 
    for (int addr = 0; addr < (1 << 7); ++addr) {
        if (addr % 16 == 0) {
            printf("%02x ", addr);
        }
 
        // Perform a 1-byte dummy read from the probe address. If a slave
        // acknowledges this address, the function returns the number of bytes
        // transferred. If the address byte is ignored, the function returns
        // -1.
 
        // Skip over any reserved addresses.
        int ret = 0;
        uint8_t rxdata;
        absolute_time_t timeout = make_timeout_time_ms(50);

        if (reserved_addr(addr))
            ret = PICO_ERROR_GENERIC;
        else
            ret = i2c_read_blocking_until(i2c_default, addr, &rxdata, 1, false, timeout);
 
        printf(ret < 0 ? "." : "@");
        printf(addr % 16 == 15 ? "\n" : "  ");
    }

    printf("Done, for real. :-)\n");

    uint8_t rxdata, reg;

    i2c_read(i2c_default, FUSB302B_ADDR, FUSB_SWITCHES0, &rxdata, 1); printf("b read FUSB_SWITCHES0: %#x ", rxdata); fusb_debug_register(FUSB_SWITCHES0, rxdata); puts(NULL);
    i2c_read(i2c_default, FUSB302B_ADDR, FUSB_SWITCHES1, &rxdata, 1); printf("b read FUSB_SWITCHES1: %#x ", rxdata); fusb_debug_register(FUSB_SWITCHES1, rxdata); puts(NULL);
    i2c_read(i2c_default, FUSB302B_ADDR, FUSB_MEASURE,   &rxdata, 1); printf("b read FUSB_MEASURE: %#x\n", rxdata);

    init();
    set_cc(TYPEC_CC_RD); /* swy: this should not be needed, as it's the default; but mark us as the UFP/sink/peripheral device */
    i2c_read_byte(i2c_default, FUSB302B_ADDR, FUSB_CONTROL0, &reg); reg |= FUSB_CONTROL0_TX_FLUSH; i2c_write_byte(i2c_default, FUSB302B_ADDR, FUSB_CONTROL0, reg);
    /* Flush the RX buffer */
    i2c_read_byte(i2c_default, FUSB302B_ADDR, FUSB_CONTROL1, &reg); reg |= FUSB_CONTROL1_RX_FLUSH; i2c_write_byte(i2c_default, FUSB302B_ADDR, FUSB_CONTROL1, reg);

    pd_reset();

    int cc1_meas, cc2_meas;
    detect_cc_pin_sink(&cc1_meas, &cc2_meas);

    /* swy: send a hard reset packet to the other side to restart the PD conversation with anything already plugged-in */
    //i2c_read(i2c_default, FUSB302B_ADDR, FUSB_CONTROL3, &reg, 1); reg |= FUSB_CONTROL3_SEND_HARD_RESET;
    //i2c_write_byte(i2c_default, FUSB302B_ADDR, FUSB_CONTROL3, reg);

    i2c_read(i2c_default, FUSB302B_ADDR, FUSB_SWITCHES0, &rxdata, 1); printf("b read FUSB_SWITCHES0: %#x ", rxdata); fusb_debug_register(FUSB_SWITCHES0, rxdata); puts(NULL);
    i2c_read(i2c_default, FUSB302B_ADDR, FUSB_SWITCHES1, &rxdata, 1); printf("b read FUSB_SWITCHES1: %#x ", rxdata); fusb_debug_register(FUSB_SWITCHES1, rxdata); puts(NULL);
    i2c_read(i2c_default, FUSB302B_ADDR, FUSB_MEASURE,   &rxdata, 1); printf("b read FUSB_MEASURE: %#x\n", rxdata);

    uint8_t switchesBackup; i2c_read(i2c_default, FUSB302B_ADDR, FUSB_SWITCHES0, &switchesBackup, 1); printf("b read FUSB_SWITCHES0: %#x ", switchesBackup); fusb_debug_register(FUSB_SWITCHES0, switchesBackup); puts(NULL);
    uint8_t measureBackup;  i2c_read(i2c_default, FUSB302B_ADDR, FUSB_MEASURE,   &measureBackup,  1); printf("b read FUSB_MEASURE: %#x\n", measureBackup);
    uint8_t counter = 0, cc1 = 0, cc2 = 0, cc1_is_bigger_than_cc2 = 0; float measured_vbus = 0.f; bool cc_tx_configured = 0;

    uint32_t  usb_pd_message_header = 0x69;
    uint32_t  usb_pd_message_buffer[10] = {0x69}; int ret;

    uint8_t buf[32] = {0x69};

    

    while (1) {
        absolute_time_t from = get_absolute_time();
        if (fusb_interrupt_callback_happened)
        {
            printf("[i] reading interrupt registers\n");

            i2c_read(i2c_default, FUSB302B_ADDR, FUSB_INTERRUPTA, &dat_int_a, 1); fusb_debug_register(FUSB_INTERRUPTA, dat_int_a);
            i2c_read(i2c_default, FUSB302B_ADDR, FUSB_INTERRUPTB, &dat_int_b, 1); fusb_debug_register(FUSB_INTERRUPTB, dat_int_b); 
            i2c_read(i2c_default, FUSB302B_ADDR, FUSB_INTERRUPT,  &dat_int,   1); fusb_debug_register(FUSB_INTERRUPT,  dat_int  );
            i2c_read(i2c_default, FUSB302B_ADDR, FUSB_STATUS1,    &dat_stat1, 1); fusb_debug_register(FUSB_STATUS1,  dat_stat1  ); puts(NULL);

            printf("[i] ---\n");

            //if (dat_int & FUSB_INTERRUPT_I_VBUSOK)
            //    run_replug = true;

            fusb_interrupt_callback_happened = 0;
        }

        // 12-bit conversion, assume max value == ADC_VREF == 3.3 V
        const float conversion_factor = 3.3f / (1 << 12);
        //uint16_t result = adc_read();
        //printf("[adc] Raw value: 0x%03x, measured voltage: %f V, actual pre-divided voltage: %f V\n", result, result * conversion_factor, result * (24.f / (1 << 12)));

        

        i2c_read(i2c_default, FUSB302B_ADDR, FUSB_STATUS1,    &rxdata, 1); ret = 0;
        
        //if ((rxdata & FUSB_STATUS1_RX_EMPTY) == 0)
            ret = get_message(usb_pd_message_buffer, &usb_pd_message_header);

        //if (ret < 0)
        //    printf("[!] error in get_message() return=%i", ret);

        if((ret > 0))
        {
            printf("[typec] get_message: ret=%i, header=%x, ndataobj=%u, id=%u, pwrole=%u, specrev=%#x, datarole=%u type=%s/%#x buf=",
                ret, usb_pd_message_header, PD_HEADER_CNT(usb_pd_message_header), PD_HEADER_ID(usb_pd_message_header),
                 (usb_pd_message_header >> 8) & 0b1,
                 (usb_pd_message_header >> 6) & 0b11, /* swy: 0b00 -> 1.0, 0b01 -> 2.0, 0b10 -> 3.0 */
                 (usb_pd_message_header >> 5) & 0b1,
                str_pdmsgtype[PD_HEADER_CNT(usb_pd_message_header) > 0][PD_HEADER_TYPE(usb_pd_message_header)], PD_HEADER_TYPE(usb_pd_message_header)
            );

            unsigned char *buf = (unsigned char *) &usb_pd_message_buffer[0];
            for (int i = 0, max = (get_num_bytes(usb_pd_message_header) - 2) + 4; i < max; i++)
                printf("%02x %s", buf[i], ((i%4)==3) ? " " : "");

            puts(NULL);


            if (PD_HEADER_CNT(usb_pd_message_header) > 0 && PD_HEADER_TYPE(usb_pd_message_header) == 0x1) /* swy: SOURCE_CAPABILITIES/0x1 */
            {
               
            /*    for (int i = 0, max = PD_HEADER_CNT(usb_pd_message_header); i < max; i++)
                {
                    uint32_t cur_powerdataobj = (usb_pd_message_buffer[i]); uint32_t cur_powerdataobj_type =  (cur_powerdataobj >> 30) & 0b1111;
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

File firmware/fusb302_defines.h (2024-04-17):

#ifndef FUSB302_DEFINES
#define FUSB302_DEFINES
#include <stdint.h>

/* I2C addresses of the FUSB302B chips */
#define FUSB302B_ADDR   (0x22 /* << 1 */)
#define FUSB302B01_ADDR (0x23 /* << 1 */)
#define FUSB302B10_ADDR (0x24 /* << 1 */)
#define FUSB302B11_ADDR (0x25 /* << 1 */)

/* Device ID register */
#define FUSB_DEVICE_ID                   0x01
#define FUSB_DEVICE_ID_VERSION_ID_SHIFT  4
#define FUSB_DEVICE_ID_VERSION_ID        (0xF << FUSB_DEVICE_ID_VERSION_ID_SHIFT)
#define FUSB_DEVICE_ID_PRODUCT_ID_SHIFT  2
#define FUSB_DEVICE_ID_PRODUCT_ID        (0x3 << FUSB_DEVICE_ID_PRODUCT_ID_SHIFT)
#define FUSB_DEVICE_ID_REVISION_ID_SHIFT 0
#define FUSB_DEVICE_ID_REVISION_ID       (0x3 << FUSB_DEVICE_ID_REVISION_ID_SHIFT)

/* Switches0 register */
#define FUSB_SWITCHES0           0x02
#define FUSB_SWITCHES0_CC2_PU_EN (1 << 7) /* swy: was PU_EN2 */
#define FUSB_SWITCHES0_CC1_PU_EN (1 << 6) /* swy: was PU_EN1 */
#define FUSB_SWITCHES0_VCONN_CC2 (1 << 5)
#define FUSB_SWITCHES0_VCONN_CC1 (1 << 4)
#define FUSB_SWITCHES0_MEAS_CC2  (1 << 3)
#define FUSB_SWITCHES0_MEAS_CC1  (1 << 2)
#define FUSB_SWITCHES0_CC2_PD_EN (1 << 1) /* swy: was PDWN_2 */
#define FUSB_SWITCHES0_CC1_PD_EN 1        /* swy: was PDWN_1 */

/* Switches1 register */
#define FUSB_SWITCHES1               0x03
#define FUSB_SWITCHES1_POWERROLE     (1 << 7)
#define FUSB_SWITCHES1_SPECREV_SHIFT 5
#define FUSB_SWITCHES1_SPECREV       ( 0x3 << FUSB_SWITCHES1_SPECREV_SHIFT)
#define FUSB_SWITCHES1_SPECREV1      (0b10 << FUSB_SWITCHES1_SPECREV_SHIFT) /* swy: added this non-flag one */
#define FUSB_SWITCHES1_SPECREV0      (0b01 << FUSB_SWITCHES1_SPECREV_SHIFT) /* swy: added this non-flag one */
#define FUSB_SWITCHES1_DATAROLE      (1 << 4)
#define FUSB_SWITCHES1_AUTO_CRC      (1 << 2)
#define FUSB_SWITCHES1_TXCC2_EN      (1 << 1)
#define FUSB_SWITCHES1_TXCC1_EN      1

/* Measure register */
#define FUSB_MEASURE            0x04
#define FUSB_MEASURE_MEAS_VBUS  (1 << 6)
#define FUSB_MEASURE_MDAC_SHIFT 0
#define FUSB_MEASURE_MDAC       (0x3F << FUSB_MEASURE_MDAC_SHIFT)

/* Slice register */
#define FUSB_SLICE                0x05
#define FUSB_SLICE_SDAC_HYS_SHIFT 6
#define FUSB_SLICE_SDAC_HYS       (0x3 << FUSB_SLICE_SDAC_HYS_SHIFT)
#define FUSB_SLICE_SDAC_SHIFT     0
#define FUSB_SLICE_SDAC           (0x3F << FUSB_SLICE_SDAC_SHIFT)

/* Control0 register */
#define FUSB_CONTROL0                0x06
#define FUSB_CONTROL0_TX_FLUSH       (1 << 6)
#define FUSB_CONTROL0_INT_MASK       (1 << 5)
#define FUSB_CONTROL0_HOST_CUR_SHIFT 2
#define FUSB_CONTROL0_HOST_CUR       ( 0x3 << FUSB_CONTROL0_HOST_CUR_SHIFT)
#define FUSB_CONTROL0_HOST_CUR1      (0b10 << FUSB_CONTROL0_HOST_CUR_SHIFT) /* swy: added this non-flag one */
#define FUSB_CONTROL0_HOST_CUR0      (0b01 << FUSB_CONTROL0_HOST_CUR_SHIFT) /* swy: added this non-flag one */
#define FUSB_CONTROL0_AUTO_PRE       (1 << 1)
#define FUSB_CONTROL0_TX_START       1

/* Control1 register */
#define FUSB_CONTROL1            0x07
#define FUSB_CONTROL1_ENSOP2DB   (1 << 6)
#define FUSB_CONTROL1_ENSOP1DB   (1 << 5)
#define FUSB_CONTROL1_BIST_MODE2 (1 << 4)
#define FUSB_CONTROL1_RX_FLUSH   (1 << 2)
#define FUSB_CONTROL1_ENSOP2     (1 << 1)
#define FUSB_CONTROL1_ENSOP1     1

/* Control2 register */
#define FUSB_CONTROL2                    0x08
#define FUSB_CONTROL2_TOG_SAVE_PWR_SHIFT 6
#define FUSB_CONTROL2_TOG_SAVE_PWR       ( 0x3 << FUSB_CONTROL2_TOG_SAVE_PWR_SHIFT)
#define FUSB_CONTROL2_TOG_SAVE_PWR1      (0b10 << FUSB_CONTROL2_TOG_SAVE_PWR_SHIFT) /* swy: added this non-flag one */
#define FUSB_CONTROL2_TOG_SAVE_PWR0      (0b01 << FUSB_CONTROL2_TOG_SAVE_PWR_SHIFT) /* swy: added this non-flag one */
#define FUSB_CONTROL2_TOG_RD_ONLY        (1 << 5)
#define FUSB_CONTROL2_WAKE_EN            (1 << 3)
#define FUSB_CONTROL2_MODE_SHIFT         1
#define FUSB_CONTROL2_MODE               ( 0x3 << FUSB_CONTROL2_MODE_SHIFT)
#define FUSB_CONTROL2_MODE1              (0b10 << FUSB_CONTROL2_MODE_SHIFT) /* swy: added this non-flag one */
#define FUSB_CONTROL2_MODE0              (0b01 << FUSB_CONTROL2_MODE_SHIFT) /* swy: added this non-flag one */
#define FUSB_CONTROL2_TOGGLE             1

/* Control3 register */
#define FUSB_CONTROL3                 0x09
#define FUSB_CONTROL3_SEND_HARD_RESET (1 << 6)
#define FUSB_CONTROL3_BIST_TMODE      (1 << 5)
#define FUSB_CONTROL3_AUTO_HARDRESET  (1 << 4)
#define FUSB_CONTROL3_AUTO_SOFTRESET  (1 << 3)
#define FUSB_CONTROL3_N_RETRIES_SHIFT 1
#define FUSB_CONTROL3_N_RETRIES       ( 0x3 << FUSB_CONTROL3_N_RETRIES_SHIFT)
#define FUSB_CONTROL3_N_RETRIES1      (0b10 << FUSB_CONTROL3_N_RETRIES_SHIFT) /* swy: added this non-flag one */
#define FUSB_CONTROL3_N_RETRIES0      (0b01 << FUSB_CONTROL3_N_RETRIES_SHIFT) /* swy: added this non-flag one */
#define FUSB_CONTROL3_AUTO_RETRY      1
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

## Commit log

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2024-02-01 Fix the pin assignments to actually make sense and match unflipped D/F.
    [psvr2-pc.kicad_sch]
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2024-02-04 Start adding the missing footprints to the schematic and editing/assigning broken 3D models, play around with PCB placement.
    [psvr2-pc.kicad_pcb, psvr2-pc.kicad_sch]
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2024-02-05 Fix the micro USB footprint, rearrange the PCB now that more pieces appear. Add funkier labels.
    [psvr2-pc.kicad_pcb, psvr2-pc.kicad_sch]
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2024-02-05 Connect more stuff together, I don't know why the buses are still causing problems, even after using the name{thing thong thung} syntax.
    [psvr2-pc.kicad_pcb, psvr2-pc.kicad_sch]
2024-02-05 Start messing with the differential pairs, I wouldn't call this routing because freerouting plugin seems buggy as heck and causes phantom traces, great.
    [psvr2-pc.kicad_pcb]
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2024-02-05 Learn to work in multiple copper layers. Swap a differential pair at the beginning. Leave a ground plane sandwiched in the middle and always keep the high speed signals at both extremes.
    [psvr2-pc.kicad_pcb, psvr2-pc.kicad_sch]
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2024-02-06 Add clearance and board fabrication limits, or learning how stuff like annular width works. Add a nice open source hardware sticker in one corner, even if I'm not particularly raising the level here.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
    [psvr2-pc.kicad_pcb]
2024-02-06 Making it all worse due to the SSTX <-> SSRX crossing. The good thing is that the positive and negative wires in each individual lane can be swapped to make routing easier.
    [psvr2-pc.kicad_pcb, psvr2-pc.kicad_sch]
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2024-02-10 Begin to shorten the board horizontally, center the headset USB-C receptacle to make it look better. Make the drawings and labels more pretty.
    [psvr2-pc.kicad_pcb]
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2024-02-12 Had some time to re-try routing the differential signals. Hopefully with the real, final connections accounting for all the cable crossing. Now also taking into account the correct trace width + sepa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
    [psvr2-pc.kicad_pcb]
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2024-02-14 Add a switch button to enter flashing mode for the Pico/RP2040. Edit the PCB to add an indication of where the please-flip-me and am-I-on LEDs should go in the future.
    [psvr2-pc.kicad_pcb, psvr2-pc.kicad_sch]
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2024-02-14 Make the oscillator thingie better, grabbed the capacitor/resistor values from a known working board for JLC's YSX321SL:
    https://www.reddit.com/r/PrintedCircuitBoard/comments/vtjyqg/thanks_for_all_your_help_my_first_pcb_design_is/
    https://raw.githubusercontent.com/diva-eng/diva-card/main/schematic.pdf
    [psvr2-pc.kicad_sch]
2024-02-14 Fix PC_USB2.0_N and PC_USB2.0_P connecting into the opposite polarity pin of the Pico. Add two ground-stitching vias to the cosmetic cooper plane with the project description, to avoid possible RF is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
    [psvr2-pc.kicad_pcb, psvr2-pc.kicad_sch]
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2024-02-19 Fixes found by @mrandtx (Marc Randolph): Just got back to looking at this a bit more.
    Not sure what you need it for (I haven't read up on the RPi), but the SW1 botton won't work with the 10k in series. Too weak against the 1k. You could make it somewhere between 0 and 100 Ohms and it should be fine.
    Also I don't know if there is ever a case for TestEn to be anything except pulled to ground - but the connection to GND on this schematic isn't making contact. And I believe you already mentioned the 2.0 USB polarity.
    [psvr2-pc.kicad_sch]
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2024-02-24 Many fixes and tweaks; switch to power the 12V for the headset with a 2.1mm center-positive DC jack. Add a polarity-protection circuit and a diode OR for the 5V/12V join to work.
    [psvr2-pc.kicad_sch]
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2024-02-24 Start fixing some stuff in the schematic after some @JX35 feedback; use the correct JLCPCB 12MHz crystal oscillator part number. https://jlcpcb.com/partdetail/Yxc-X322512MSB4SI/C9002
    [psvr2-pc.kicad_sch]
2024-02-24 Start fixing some stuff in the schematic after some @JX35 feedback; use bigger resistor values in the 24V to 3.3V voltage divider. Use something that can withstand 4.404 mA of current.
    RATIO ERROR
    RL RH Rtot Current Power Ratio Vout Vin Absolute % ppm Tolerance (%)
    750 4K7 5450 4.404 mA 105.688 mW 0.137614679 3.302752294 23.980000000 -0.000114679 0.083 834 6.097985
    430 2K7 3130 7.668 mA 184.026 mW 0.137380192 3.297124601 24.020930233 0.000119808 -0.087 871 6.099643
    620 3K9 4520 5.310 mA 127.434 mW 0.137168142 3.292035398 24.058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
    [psvr2-pc.kicad_sch]
2024-02-25 Start fixing some stuff in the schematic after some @JX35 feedback; add 4K7 pull up resistors to the I2C type-C lines and small capacitors on the CC lines.
    [psvr2-pc.kicad_sch]
2024-02-25 Start fixing some stuff in the schematic after some @JX35 feedback; fix the crystal oscillator tag. Fix the wrong/badly copy-pasted 100M Ohms pull ups/down on the PC/sink side. We need to use 1M Ohm 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
    [psvr2-pc.kicad_sch]
2024-02-25 Start fixing some stuff in the schematic after some @JX35 feedback; try to fix the MOSFET power switch section and add some much-needed resistors. still need to properly simulate the whole power circ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
    - The 12V feedback resistors look to small to me, they'd burn 200mW at 12V; small SMD resistors can't handle that and it's a waste
    - The FUSB302 datasheet specifies 4K7 external pullups on the communication lines, I'd add them because internal pullups of MCUs are usually quite weak. It also specifies tiny capacitors on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
    [psvr2-pc.kicad_sch]
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2024-02-26 Mess around trying to give every component some kind of footprint, even if they are too big and impractical right now, to get a good intuition of what we would need to do, board-size wise.
    [psvr2-pc.kicad_pcb, psvr2-pc.kicad_sch]
2024-02-28 Change all the P MOSFETs to Si2301CDS_1_1, and use the correct SOT-23 footprint.
    [psvr2-pc.kicad_pcb, psvr2-pc.kicad_sch]
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2024-02-29 Start working on learning how to route normal components like the QSPI flash to the microcontroller. Fix the annular rings too big warnings.
    [psvr2-pc.kicad_pcb]
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2024-02-29 Mess around with the silkscreen art over the high-speed lanes and fix the ground plane at the edges.
    [psvr2-pc.kicad_pcb]
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2024-02-29 More routing, fix the funky USB2 main routing by moving it into the power layer, screw it.
    [psvr2-pc.kicad_pcb]
2024-02-29 Make the SWD pin header have another pin for ground. Reduce the DRC error count a bit more, add more track leeway, reduce polygon overlaps and add missing connections, mainly 3V3 power.
    [psvr2-pc.kicad_pcb, psvr2-pc.kicad_sch]
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2024-02-29 Swap to GPIOs to make routing slightly less messy. Make the Open Source Hardware logo line up with the 12V track. Other extra circuiting.
    [psvr2-pc.kicad_pcb, psvr2-pc.kicad_sch]
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2024-02-29 Fix the VBUS_5V net not getting renamed into the PCB editor from the schematic due to an error with the diode footprint. Change it and now it works. Add the 5V power traces and keep connecting more s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
    [psvr2-pc.kicad_pcb, psvr2-pc.kicad_sch]
2024-02-29 More DRC fixes, make the default annular size 0.4mm instead of 0.25. I messed up and all the new vias had this, causing a bunch of regressions. Almost there. :)
    [psvr2-pc.kicad_pcb]
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2024-03-01 Try to fix the third layer (power plane) to actually have a ground fill under/over the high-speed differential lines. route the SWD/SWCLK lines.
    [psvr2-pc.kicad_pcb]
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2024-03-01 Fix the last two or three clearance errors in the tiny traces moving inside the USB Type-C port.
    [psvr2-pc.kicad_pcb]
2024-03-01 Fix silk component tag overlap warnings and readability issues; move them around a bit.
    [psvr2-pc.kicad_pcb]
2024-03-01 Fix some overlapping component tags and make them readable. No more DRC errors or warnings. Yay! The next step is to look again at the schematic and flesh out the component footprints, double check t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
    [psvr2-pc.kicad_pcb]
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2024-03-01 Increase the via size to where it makes sense, and space is not too constrained. Mostly to .4mm, make the power vias also thicker. Fix the 90-degree corners in the AUX LVDS terminator traces, like Ma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
    > Nice. Minor comments: It's difficult to tell from the image, but the vias seems surprisingly close to the pads for U1 and U2. Guessing it's probably fine, and it just looks worse than it is. Even for low speed signals, 90 degree trace corners are rare (especially to the right of U1, and above C20) - to minimize questions from the board house, I'd try to chamfer them even a tiny bit - even if you have to slide R1 and R2 away a bit more (I say that with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
    [psvr2-pc.kicad_pcb]
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2024-03-01 Rename the switch component to SW1, fix the crystal footprint to use the actual one from JLC, instead of some smaller Abracom one I chose randomly. Add more JLC IDs, to the crystal and VBUX_5V to 3V3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
    [psvr2-pc.kicad_pcb, psvr2-pc.kicad_sch]
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2024-03-04 Add the USB Type-C Part # to the schematic. Edit the connector footprints to move the cutout lines into a different layer to avoid problems with the general board shape:
    https://forum.kicad.info/t/change-layer-of-multiple-selected-items-in-footprint-editor/12184/3
    https://forum.kicad.info/t/footprints-with-edge-cuts/35659
    Add a recessed cut for the micro USB thing, and move the DisplayPort thing a bit further into the edge to avoid problems. Haven't moved the traces yet, what a mess this whole footprint business is. :(
    [psvr2-pc.kicad_pcb, psvr2-pc.kicad_sch]
2024-03-04 Rework the power plane (third layer), which stopped losing contact in the 3V3 fill separated by that ground fill. Add some funny text tags in the copper as easter eggs. :)
    Fix DRC errors and warnings.
    [psvr2-pc.kicad_pcb]
2024-03-04 Make the filled out areas in all the layers more comprehensive, rounded, and giving enough margin from the cutout area to avoid shorting stuff out, like @mrandTX mentioned. Thanks to him.
    [psvr2-pc.kicad_pcb]
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2024-03-06 Fix the four switch pins for the BOOTSEL switch in the schematic. Make the DP-AUX jumpers have rounded corners. No more DRC violations again.
    [psvr2-pc.kicad_pcb, psvr2-pc.kicad_sch]
2024-03-06 Switch the footprint of the oscillator capacitors from 0805 to the smaller 0603 shape, add part numbers. As those are "basic" parts on JLC. Name the inner AUX traces before the jumpers so that we can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
    [psvr2-pc.kicad_pcb, psvr2-pc.kicad_sch]
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2024-03-06 Fix the DRC error for the AUX pair now touching the safety area for a close via before starting with the skew tunning and squiggles.
    [psvr2-pc.kicad_pcb]
2024-03-06 Fix all the reported ERC (the schematic error checker) problems. Mark a bunch of pins as not connected and move the power flag to the LDO (DC-DC 5V to 3V3 converter) to make it shut up.
    [psvr2-pc.kicad_sch]
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2024-03-07 Make the 3V3 status LED white and the headset ready one green. Now they are reversed. Use yellow for the flip connector LED instead of orange. Set the component IDs.
    [psvr2-pc.kicad_sch]
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2024-03-07 Get rid of the pin header 3D model by setting the scale to zero, fix the courtyard a bit, don't include it in the bill of materials: https://forum.kicad.info/t/how-to-remove-3d-model-but-keep-pads/28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
    [psvr2-pc.kicad_pcb, psvr2-pc.kicad_sch]
2024-03-07 Fix the white LED part number and use a much bigger resistor to make it dimmer. As this one is kind of strong. Hopefully things end up looking alright.
    [psvr2-pc.kicad_pcb, psvr2-pc.kicad_sch]
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2024-03-07 Update the LVDS-M transceiver chip to the correct A model, as @mrandTX said: SN65MLVD200ADR:
    --
    @mrandTX
    For anyone following along, and Swyter in particular, the following are all identical part numbers for 200A. R specifies that it comes in a tape and reel packaging. G4 is extra green, although in this case, saying G4 doesn't matter - you seem to get G4 regardless if you specify it.
    SN65MLVD200AD
    SN65MLVD200ADG4
    SN65MLVD200ADR
    SN65MLVD200ADRG4
    [psvr2-pc.kicad_sch]
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2024-03-09 More resistor adjustments to fit the real-life requirements of cheap components. Add two resistors in series to approximate the right current value in LEDs. Not happy with this, but what are you goin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
    [psvr2-pc.kicad_pcb, psvr2-pc.kicad_sch]
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2024-03-09 Change a few components to make them manufacturable at the lowest cost (basic ones). Change some footprints, add attributes to compensate for the wrong rotation and offset in many parts. Change a cap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
    DC 12 jack notes for the top-left cursor position:positions
    bad/before: 15.81, -58.9
    good/after: 12.83,-61.39
    >>> 12.83-15.81
    -2.9800000000000004
    >>> -61.39--58.9
    -2.490000000000002
    >>>
    [psvr2-pc.kicad_pcb, psvr2-pc.kicad_sch]
2024-03-09 Fix the wrong units being used in the 470u capacitors; they should be 470pF. Fix more JLC pick and place machine rotation compensation fields. Add more part number hints and use the right suffix for 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
    [psvr2-pc.kicad_pcb, psvr2-pc.kicad_sch]
2024-03-09 Fix the footprints in the schematic part, I only changed them in the PCB, so when sync'ing the schematic to the PCB it was erroring out and these components were skipped altogether. Add more LCSC par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
    [psvr2-pc.kicad_pcb, psvr2-pc.kicad_sch]
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2024-03-10 Hey, look. Got the power circuit simulation to work on KiCad 8 by starting a new project that uses the transistors in the simulation category. Everything seems to more or less work as expected with t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
    https://cdn.discordapp.com/attachments/711640844222070836/1216298802143563786/imagen.png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
    [simulation.kicad_sch]
2024-03-10 Great, this doesn't work anymore after using the real library model. I'll need to see what's going on.
    [simulation.kicad_sch]
2024-03-10 Welp, using the actual model library file it stops working, great. If the P-MOSFET is on it works properly, but when off there seems to be a problem with the diode clamping it to 2.60V. I don't know 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
    [simulation.kicad_sch]
2024-03-10 Fix the DP-AUX emu resistor units. Thanks to @JX35 for noticing.
    > The values for the diff pair termination are different to mine - R13, R14 I have 100K; R9, R10, R15, R16 I have 51 ohm. Is there a reason? I do have reasons for choosing those values
    > No reason, I'm just stupid and can't read the units properly. Thanks.
    [psvr2-pc.kicad_sch]
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2024-03-10 Switch the P-MOSFETs from Si2301CDS to AO3401A. These seem to have a smaller on resistance, so it reduces the voltage drop when going through three of them. They also seems to work fine in the simula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
    I haven't been paying attention lately, any new schematics?
    Found one form 3 days ago:
    the FUSB302 datasheet calls for 200-600pF capacitance on each CC line - I don't see a reason not to add it
    LED resistors - I've used 510 ohm resistors on the DP-aux-emu for blue LEDs and they were brighter than would have been necessary. Hard to give an exact recomendation - your values are calculated right and won't damage them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
    [psvr2-pc.kicad_sch]
2024-03-11 I know why the simulation didn't work; I applied the P-MOSFET model to the Q6/HMD_ENABLE_BUS NPN transistor. I'm stupid, as usual. :)
    [simulation.kicad_sch]
2024-03-11 Now the simulation works again after changing the component and doing other stuff I don't understand. Raise the NPN resistor from 1K to 7K ohms to reduce the gate-source voltage difference and avoid 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
    [simulation.kicad_sch]
2024-03-11 Add a resistor voltage divider in the reverse voltage protection simulation to protect the gate and avoid Vgs (gate-source pin difference)
    getting too big and burning the MOSFET, usually the Vds limit (-30V) is bigger than the Vgs one (here ±12V):
    That way we can withstand until 30V, in theory.
    https://electronics.stackexchange.com/a/61699/196330
    https://aosmd.com/sites/default/files/res/datasheets/AO3401A.pdf
    [simulation.kicad_sch]
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2024-03-15 Start to learn how to add the SPICE model parameters to simulate a TVS voltage protection diode array and confirm it works, not working yet, getting there.
    [simulation.kicad_sch]
2024-03-17 Mess around a bit more with the simulation. can't say I really know what's wrong or why the simulation isn't clamping anything. Worth studying more in the future.
    [simulation.kicad_sch]
2024-03-17 Add two extra pads in the back of the board, exposing the ADC2 and ADC3 pins. Just for kicks. Might be useful to tap into the AUX or Power Delivery signals and maybe skip an expensive chip or two in 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
    [psvr2-pc.kicad_pcb, psvr2-pc.kicad_sch]
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2024-03-17 Fix the power gating simulation again, remove all the custom properties and impedance from the 12V power source. Switch from the generic NPN transistors to MMBT2222A.
    [psvr2-pc.kicad_pcb, simulation.kicad_sch]
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2024-03-17 Adjust the board layout and orientation for the resistor dividers and polarity-reversal protection MOSFET. Adjust more of the silkscreen and move a bunch of funky component tags around.
    [psvr2-pc.kicad_pcb, psvr2-pc.kicad_sch]
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2024-03-17 Update the resistor sizes to make them cheap. Use 51K/8K2 for the 24V to 3.3V divider. Use 6K8 instead of 7K. Update the simulation, seems to still work fine. Add the LCSC Part # to the NPN transisto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
    Currently available resistor sizes as basic parts:
    5.1kΩ 6.8kΩ 8.2kΩ
    47kΩ 51kΩ 68kΩ
    [psvr2-pc.kicad_pcb, psvr2-pc.kicad_sch, simulation.kicad_sch]
2024-03-17 Remove more potentially messy LCSC Part # attributes from resistors that have since changed values and may end up selecting the wrong resistance and getting a broken board. Looking good.
    [psvr2-pc.kicad_pcb]
2024-03-17 Move the ugly impedance matching notes, indications and text from the User Comments layer to the User.1 layer. So that it doesn't show in the 3D renderer. Update the preview image, link it in the Rea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
    [psvr2-pc.kicad_pcb]
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2024-03-20 Make R41 not get too close to the edge of the board; move the MOSFET up a bit. Move the comments written in copper in the second layer away from the bottleneck area. Make the wiggly paths in the back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
    [psvr2-pc.kicad_pcb]
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2024-03-20 Use relative paths to retrieve the 3D models. Get rid of the ugly EasyEDA watermarks in the models with the help from FreeCAD.
    Download the more fleshed out 3D model for the USB-C receptacle with actually-modeled pins from SnapEDA, the official one from Molex sucks: https://www.snapeda.com/parts/105450-0101/Molex/view-part/?welcome=home
    [psvr2-pc.kicad_pcb]
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2024-03-21 Use the correct pinout for the AMS1117-3.3 5V to 3V3 converter and reorganize the nearby PCB components; the thermal tab is 3V3 instead of ground, everything is switched around respect to conventiona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
    Make the HMD_VBUS via bigger to sink more current.
    [psvr2-pc.kicad_pcb, psvr2-pc.kicad_sch]
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2024-03-27 Make the edge cut lines straighter, especially in the right part, which I just previously eyeballed. Try to improve the balance of the amount of copper of some of the the SMT pads, so that one doesn'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
    @JX35: https://discord.com/channels/556527313823596604/711640844222070836/1220657104897966090
    Looking at it, there's nothing that should make the board not work - these are just nitpicks - which is what I suspect is the reason you didn't get any comments. I'd have a few suggestions for the schematic, but they'd be more of "here's how I do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
    [psvr2-pc.kicad_pcb]
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2024-03-27 Adjust the small labels in the front silk mask, make them more uniform, even if they are w-i-d-e now. Fix the new components in the Fab layer. :)
    [psvr2-pc.kicad_pcb]
2024-03-28 In the final production file, the high-speed differential pairs in the top copper layer next to J3 and J2 had a missing sliver due to tolerances that changed the length and width of the trace. They h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
    [psvr2-pc.kicad_pcb]
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2024-03-28 Redraw the HMD_USB_2.0 low-speed differential pair, which is optional, and probably not needed for anything. But use the correct trace width and spacing for impedance matching. Add ground in the thir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
    [psvr2-pc.kicad_pcb]
2024-03-28 Update the ground plane in the third layer a bit more to remove copper from where it may cause issues.
    [psvr2-pc.kicad_pcb]
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2024-04-11 Firmware: Fix the microcontroller getting stuck on i2c_read_blocking(). Turns out that `i2c_default` pointed to `i2c1_inst` instead of `i2c0_inst`. There are two hardware I2C blocks and some pins onl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
    So yeah, set PICO_DEFAULT_I2C to 0 and Bob's your uncle. It's always something like this. I thought the 1 meant that the macro guard was TRUE.
    I guess that means that all the pieces of the puzzle are there, no hardware respin necessary for Power Delivery. Now it's just a matter of c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
    [psdaptwor.h]
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2024-04-12 Firmware: Properly explain in the custom board header what the hardware block indices mean, and why they are important. To avoid further future problems. Change the `PICO_DEFAULT_UART` to hardware bl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
    [main.c, psdaptwor.h]
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2024-04-12 Firmware: Fiddle with the PICO_NO_FLASH variable set to 1 to generate a .uf2 file that doesn't hammer the flash write cycles. Add more fast launch options to quick flash/execute on RAM and reboot the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
    [main.c]
2024-04-12 Firmware: Start messing around with the first I2C writes to the FUSB302 USB-C controller by forcing a soft reset and seeing what happens. Boy, the recompile-debug-flash-log toolchain is pure garbage.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
    [fusb302_defines.h, main.c]
2024-04-12 Firmware: Configure the FUSB302 USB-C controller by flushing the buffers, resetting the Power Delivery logic and reading the SWITCHES AND MEASURE registers to get a good approximation of how it's lai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
    [main.c]
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2024-04-14 Firmware: Fix the FUSB controller chip voltage comparator voltage number being off by one index due to a self-incrementing thingie. Set both MOSFET pins to low, now that I'm testing Type-C VBUS backf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
    [main.c]
2024-04-14 Firmware: Fix FUSB controller interrupts; I was using the wrong pin (3 instead of 2). Go figure.
    [main.c]
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2024-04-15 Firmware: Managed to detect the CC lines, compare them, and blink the amber LED when plugged in the "wrong" direction. Next up will be setting up the data and power roles and start talking some BMC/P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
    [main.c]
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2024-04-15 Firmware: Fix the interrupts not triggering because I was not reading (an hence clearing) the FUSB_INTERRUPT and FUSB_INTERRUPTB registers. Found while reading the ChromeOS EC implementation, link it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
    [main.c]
2024-04-15 Firmware: Try to improve the FUSB302 glue logic a bit more, start reading the FIFOS register, still nothing. I'm definitely missing something pull-up/down related and a bunch of register writes. Dela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
    [main.c]
2024-04-16 Firmware: Toggling the hot-plug-detection pin on and off momentarily freezes the display driver and cursor, probably while trying to read an unresponsive DP-AUX channel. I guess that does something, 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
    Making the pulses shorter completely resets the cursor position on Windows and freezes everything for seconds, I think the graphics card stops transmitting altogether, absolute denial of service. Had to unplug it manually.
    [main.c]
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2024-04-16 Firmware: Improve the flag print system to properly handle printing | when needed and raw numbers when there are unknown flags remaining in the number. Add two missing flags in the header.
    [i] USB-C controller interrupt request: 2 [INTERRUPTA]: I_TOGDONE, [INTERRUPTB]: 0, [INTERRUPT]: I_VBUSOK, [STATUS0]: VBUSOK|BC_LVL1|BC_LVL0, [STATUS0A]: POWER3|POWER2, [SWITCHES0]: PDWN_2|PDWN_1, f write ret: 0
    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
    [fusb302_defines.h, main.c]
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
